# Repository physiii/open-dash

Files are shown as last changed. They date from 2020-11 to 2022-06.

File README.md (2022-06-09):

### Objective

Provide an open source platform for vehicle information and entertainment. 

Daughterboard firmware is designed around FreeRTOS. Supports CANbus and J1850 protocols and many functions such as HVAC control, battery monitoring, vehicle status and statistics over wifi. Uses driver circuits for various actuators around the car. 

Front end software is designed to run on Linux. I recommend Ubuntu for the main computer. 

GUI is made using NodeWebkit and communicates with a custom daughterboard for interfacing with the vehicle.

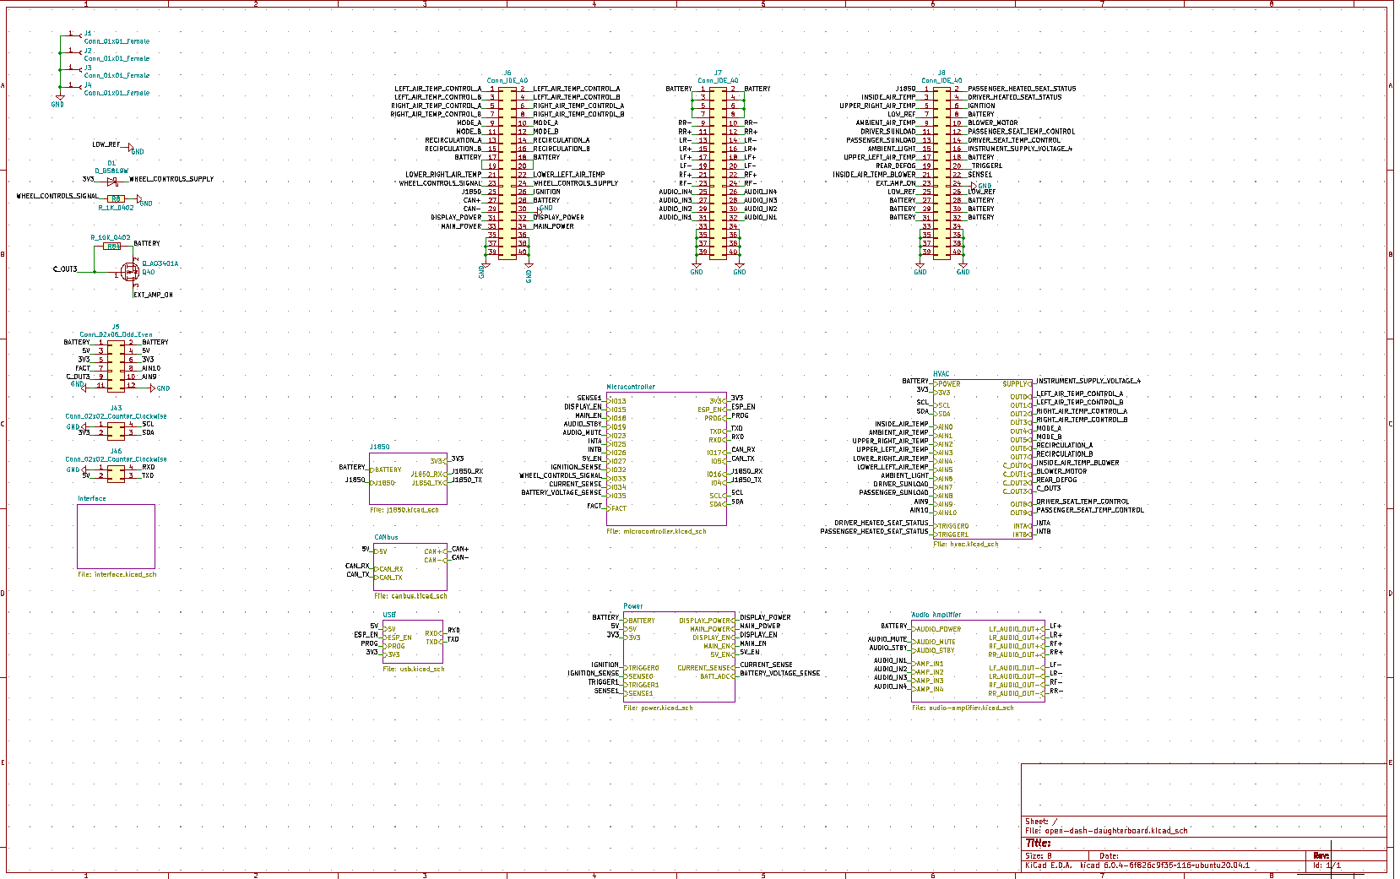
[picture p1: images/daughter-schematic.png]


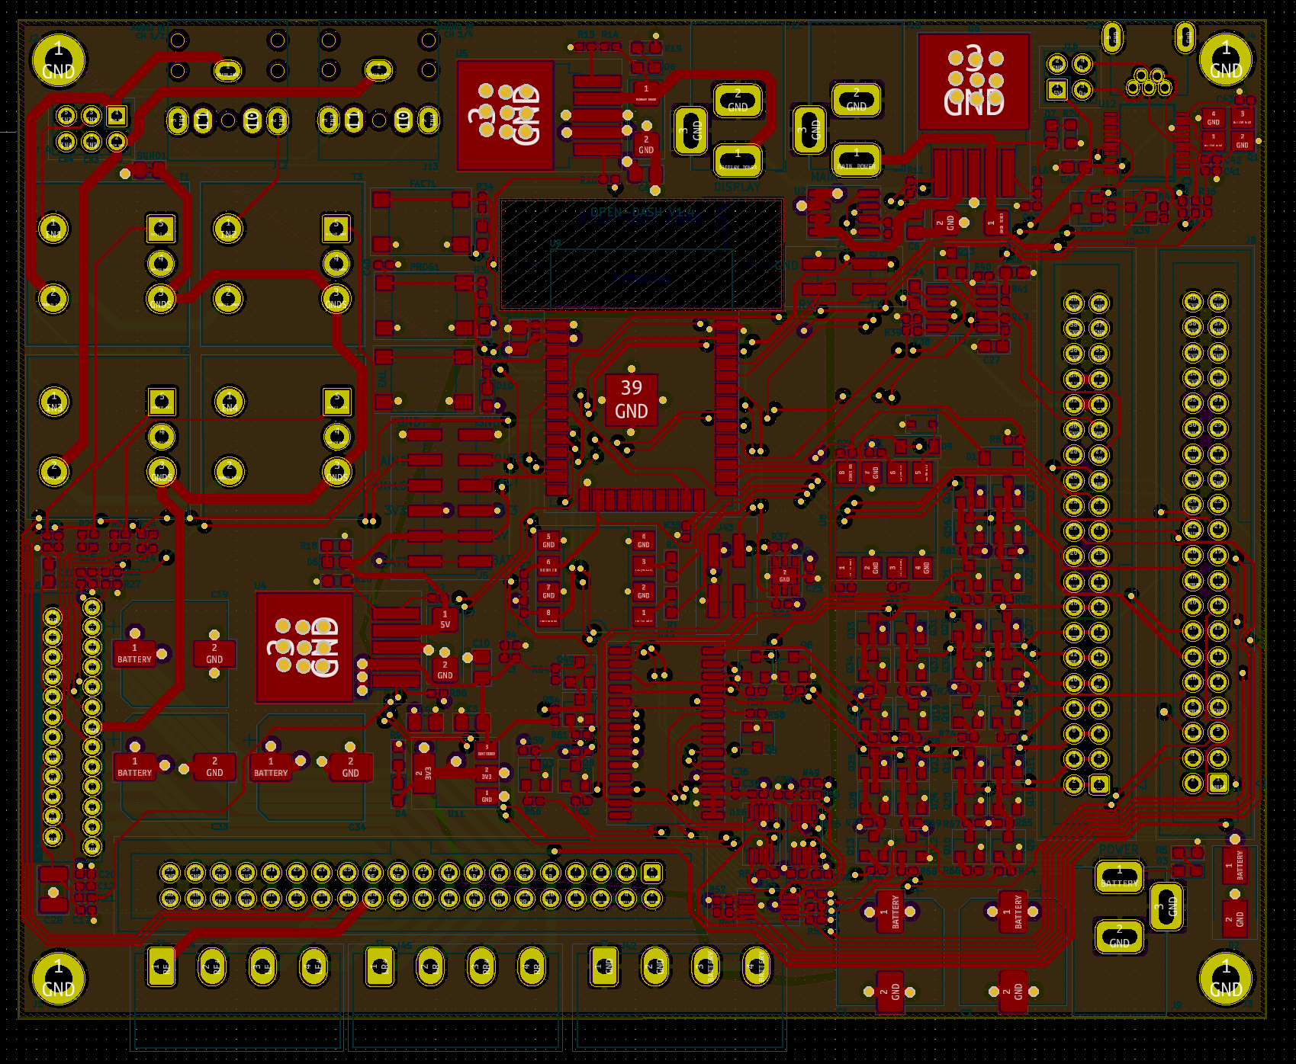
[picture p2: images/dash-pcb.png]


### Install OS
Download ubuntu 21.10 and create boot disk  
Press esc to get to boot menu  
Boot manager  
Choose flash drive  
Choose Install ubuntu
Choose erase disk and install ubuntu  
Remove flash drive and reboot  

### Setup OS
Set no keyring passwd  
Disable Power Savings   
sudo visudo /etc/sudoers: 
```
%sudo   ALL=(ALL:ALL) NOPASSWD:ALL  
```

```
sudo usermod -a -G dialout $USER
sudo usermod -a -G audio $USER
```
Add startup programs  
```
pm2 start /usr/local/src/open-dash/service/index.js --time --name dash
nw /usr/local/src/open-dash
```

### Display

Set scale to 200%  
Rotate to portrait mode
Settings > Appearance > Position on screen: Bottom
```
sudo cp /usr/local/src/open-dash/scripts/99-touch.rules /etc/udev/rules.d/99-touch.rules
```

### Install Dependencies
```
sudo apt install -y curl
curl -sL https://deb.nodesource.com/setup_14.x | sudo -E bash -
sudo apt update
```

```
sudo wget -qnc https://repo.nordvpn.com/deb/nordvpn/debian/pool/main/nordvpn-release_1.0.0_all.deb
sudo dpkg -i ./nordvpn-release_1.0.0_all.deb
```
```
wget -q -O - https://dl-ssl.google.com/linux/linux_signing_key.pub | sudo apt-key add -
echo 'deb [arch=amd64] http://dl.google.com/linux/chrome/deb/ stable main' | sudo tee /etc/apt/sources.list.d/google-chrome.list
sudo apt update
```

```
sudo apt-get -y install gnupg
wget -qO - https://www.mongodb.org/static/pgp/server-4.4.asc | sudo apt-key add -
echo "deb [ arch=amd64,arm64 ] https://repo.mongodb.org/apt/ubuntu focal/mongodb-org/4.4 multiverse" | sudo tee /etc/apt/sources.list.d/mongodb-org-4.4.list
```

```
sudo apt update && sudo apt upgrade -y

sudo apt install -y \
  tmux git nodejs sshfs nmap cmake pv vlc pithos gimp librecad resolvconf openssh-server \
  net-tools v4l-utils clementine net-tools kodi nordvpn vlc-plugin-bittorrent \
  libgconf-2-4 sshpass git nodejs dnsmasq hostapd tmux xdotool libudev-dev \
  python-setuptools python3-dev libssl-dev libasound2-dev nmap ffmpeg \
  build-essential cmake pkg-config libjpeg-dev libtiff5-dev libatomic1 \
  libavcodec-dev libavformat-dev libswscale-dev libv4l-dev libxvidcore-dev libx264-dev libfreetype6-dev \
  libatlas-base-dev gfortran python3-dev libavcodec-dev libavformat-dev python3-pip \
  libasound-dev portaudio19-dev libportaudio2 libportaudiocpp0 \
  google-chrome-stable speedtest-cli mongodb-org \

```

```
sudo npm install -g nw-gyp
sudo npm install -g pm2 --unsafe-perm=true --allow-root
sudo snap install atom --classic
sudo snap install blender --channel=beta --classic
```

```
sudo apt install -y apt-transport-https curl
sudo curl -fsSLo /usr/share/keyrings/brave-browser-archive-keyring.gpg https://brave-browser-apt-release.s3.brave.com/brave-browser-archive-keyring.gpg
echo "deb [signed-by=/usr/share/keyrings/brave-browser-archive-keyring.gpg arch=amd64] https://brave-browser-apt-release.s3.brave.com/ stable main"|sudo tee /etc/apt/sources.list.d/brave-browser-release.list
sudo apt update
sudo apt install -y brave-browser
```
### kicad
```
sudo add-apt-repository --yes ppa:js-reynaud/kicad-5.1
sudo apt update
sudo apt install -y --install-suggests kicad

mkdir ~/circuits
cd ~/circuits
git clone https://github.com/physiii/kicad-parts
# add symbol and footprint paths
```
### esp32
```
sudo ln -s /usr/bin/python3 /usr/bin/python

mkdir -p ~/esp
cd ~/esp
git clone --recursive https://github.com/espressif/esp-idf.git

cd ~/esp/esp-idf
./install.sh

echo "alias get_idf='. $HOME/esp/esp-idf/export.sh'" >> ~/.bashrc

source ~/.bashrc
get_idf

cd ~/esp
cp -r $IDF_PATH/examples/get-started/hello_world .
cd ~/esp/hello_world
idf.py set-target esp32
idf.py menuconfig
```

### audio
```
cd ~
git clone https://github.com/physiii/ardour-sessions

```
sudo nano /etc/security/limits.conf
```
  @audio          -       rtprio          99
```
```
sudo apt install -y qjackctl pulseaudio-module-jack libjack0 jackd jack-tools \
linux-lowlatency ardour a2jmidid libjack-dev pavucontrol \
```
## Jack
set interface  
Settings -> MIDI Driver: seq  
Options -> execute script after startup: pactl load-module module-jack-sink;pactl load-module module-jack-source;pactl set-default-sink jack_out  
Misc -> start JACK audio service on application startup  
```
pamcd set-default-sink jack_out
```
```
sudo apt install -y \
calf-plugins libtool autoconf libexpat1-dev libglib2.0-dev libfluidsynth-dev \
jackd libjack-dev libglade2-dev lv2-dev yoshimi ams \
blop caps cmt fil-plugins rev-plugins swh-plugins tap-plugins \
invada-studio-plugins-lv2 mda-lv2 swh-lv2 \
blepvco mcp-plugins omins so-synth-lv2 lingot \
```
## MIDI

```
pip3 install python-rtmidi pyserial mido
git clone https://github.com/physiii/wireless-midi
```

###  Popcorn
```
sudo chown -R ${USER}:${USER} /usr/local/src
cd /usr/local/src
git clone https://github.com/popcorn-official/popcorn-desktop
cd popcorn-desktop
sudo npm install -g gulp
npm install
gulp build
gulp run
nw .
```
### NW.JS
```
sudo chown -R ${USER}:${USER} /usr/local/src
cd /usr/local/src  
wget https://dl.nwjs.io/v0.54.0/nwjs-sdk-v0.54.0-linux-x64.tar.gz
tar -zxvf nwjs-sdk*  
cd nwjs-sdk*  
sudo ln -s /usr/local/src/nwjs-sdk-v0.54.0-linux-x64/nw /usr/bin/nw  
```
### Install Software
```
sudo chown -R ${USER}:${USER} /usr/local/src
cd /usr/local/src
git clone https://github.com/physiii/open-dash
cd open-dash
npm install
npm run build
```

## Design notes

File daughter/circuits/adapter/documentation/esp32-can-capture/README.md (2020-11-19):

this program just prints CAN frames so you can capture them with "make monitor"

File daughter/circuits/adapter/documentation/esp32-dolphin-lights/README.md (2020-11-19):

let a Dolphin drive the WS2812 LEDs via a serial BT connection to the ESP32

based in part on <https://github.com/FozzTexx/ws2812-demo>

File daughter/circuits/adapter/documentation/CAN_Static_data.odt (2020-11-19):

Listing of all IDs that were broadcasting the same data in a ~30 second period without changing, engine was running

Known static conditions:

Outside air temp: 103*F

Odometer: 904 miles

Time/date: 7:01am, Jan 1 2017

Gear: park

ESC mode: on

AC: on

AC fan: on

Speed: 0 mph

6314000: unknown: 0000000000000000

4294001: unknown: 0000B30000000000

421400B: unknown: 00863E0400000000

6214000: Lights, maybe: 0404400000570B00

C054003: unknown: 047005AE815A0000

63D4000: unknown: 9F56000018B70000

4394000: unknown: 00000002

4214006: ESC mode: 0000000000000006

621400A: unknown: 0400

6254000: unknown: 80FFFF00FFFFFF00

6314003: unknown: 0010700000000000

621401A: unknown: 0005010092000000

2214000: unknown: 000000000000

A3D4003: unknown: 2CA51004D0000000

6284000: Steering wheel controls: 0000000000000000

A354003: unknown: 2CA51004D0000000

6314018: Reverse: C000000000000000

62BBF00: unknown: 0000000000000000

A194003: unknown: 0000400000000000

C394003: unknown: C302000008016000

E094000: unknown: 001E05401C4B

E094003: unknown: 001E

E09400A: unknown: 001E

E094018: unknown: 001E

E09401A: unknown: 000E

E094020: unknown: 000A

2294000: unknown: 0000000000000000

C214003: Time/date string: 070101012017

*********************************************************

Another static dump, but with engine off (only one new ID):

4294001: unknown: 0000B30000000000

421400B: unknown: 00863E0400000000

3029100: unknown: 0000000000000000

621401A: unknown: 0005010092000000

4214001: unknown: 0081508B00000000

6214000: Lights, maybe: 0404480000570B00

621400A: unknown: 0400

C054003: unknown: 047005AE895A0000

63D4000: unknown: 9F4F00001AB70000

4394000: unknown: 00000002

4214006: ESC mode: 0000000000000000

6254000: unknown: 00FFFF00FFFFFF00

6314003: unknown: 0010700000000000

2214000: unknown: 000000000000

A3D4003: unknown: 2CA5100500000000

6284000: Steering wheel controls: 0000000000000000

A354003: unknown: 2CA5100500000000

62BBF00: unknown: 0000000000000000

A194003: unknown: 0000400000000000

C394003: unknown: C302000008016000

E094000: Key/ignition status probably: 001E05401C4B

E09400A: unknown: 001E

E094003: unknown: 001E

E094018: unknown: 001E

E09401A: unknown: 000E

E094020: unknown: 000A

6314018: Reverse: C000000000000000

2294000: unknown: 0000000000000000

C214003: Time/date string: 070701012017

***********************************************

IDs that change upon pressing brake:

4294001

421400B

2214000

63D4000

4214001 is more or less static with engine off, but does change as brake pedal is pressed. However, it changes constantly when engine is running. Perhaps this is brake booster pressure.

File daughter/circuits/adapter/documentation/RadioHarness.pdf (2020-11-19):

# Connector: Amp PA66−GF35 (PBT−GF15)

# > PBT−GF15 < B1

### RETURN (COMMON)

### CAMERA

### CAMERA SIGNAL

### SHIELD

### CAMERA

CAN
HIGH

LOW

CAN

CHASSIS
GROUND

12vDC
UNSWITCHED

# SPEAKERS

# NEG

# POS

RR− | FR− | FL− | RL−

− MIC +

BL

R REF
IN IN

DET
IN

L
IN

# AUX

3 | 4 | 5

13 18

29

1 | 2 | 6 | 7 | 8 | 9 | 10
11 | 12 | 14 | 15 | 16 | 17 | 19 | 20
21 | 22 | 23 | 24 | 25 | 26 | 27 | 28 | 30
31 | 32 | 33 | 34 | 35 | 36 | 37 | 38 | 39 | 40 | 49 | 50 | 51 | 52
45 | 46 | 47 | 48
41 | 42 | 43 | 44

RADIO ON
(NC)

+
(NC)

NOT CONNECTED ON 2018+ MODELS. LATE MODELS USE CANBUS MESSAGES TO SEND IGNITION/KEY STATUS

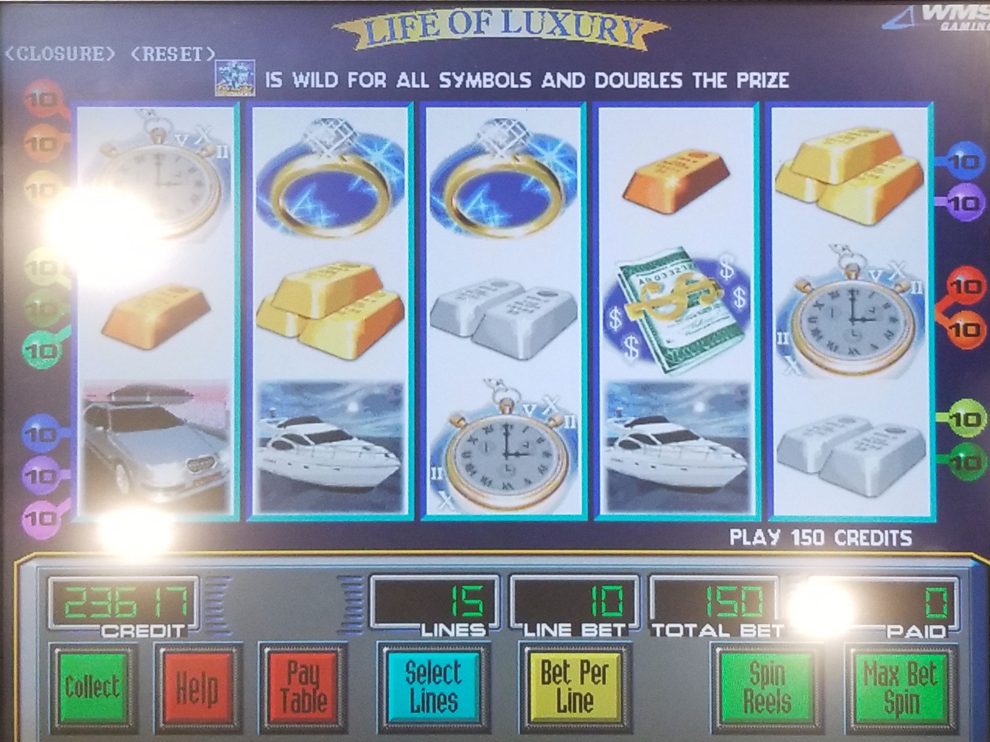
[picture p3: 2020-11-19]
src/assets/game-board-mockup.jpg

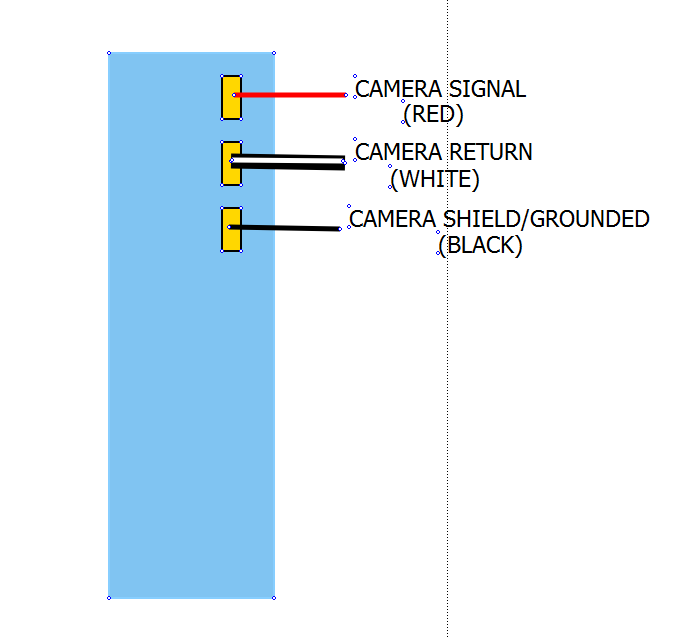
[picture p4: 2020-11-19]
daughter/circuits/adapter/documentation/CameraHarnessRadio_C.png

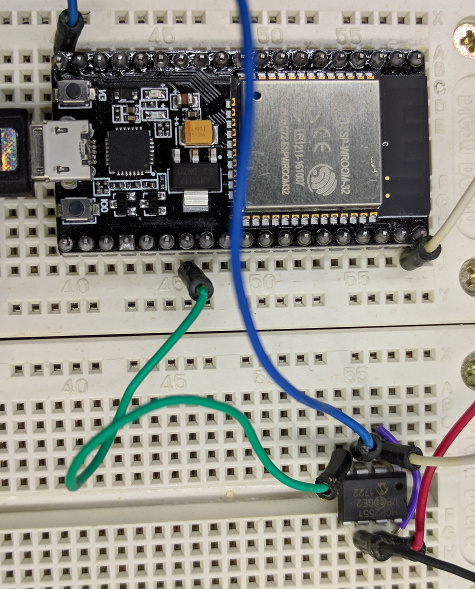
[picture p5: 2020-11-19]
daughter/circuits/adapter/documentation/ESP32-MCP2551.jpg

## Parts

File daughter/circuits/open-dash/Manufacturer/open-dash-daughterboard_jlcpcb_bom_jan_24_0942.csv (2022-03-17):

Comment | Designator | Footprint | LCSC
C_0.1uF | C13,C14,C15,C16,C21,C25 | Capacitor_SMD:C_0402_1005Metric_Pad0.74x0.62mm_HandSolder | C1525
C_470nF | C18 | Capacitor_SMD:C_0603_1608Metric_Pad1.08x0.95mm_HandSolder | C1623
C_470uF | C1,C2,C19,C33,C34 | Capacitor_SMD:CP_Elec_10x10 | C3350
C_1uF | C11,C12,C20,C23,C40 | Capacitor_SMD:C_0402_1005Metric_Pad0.74x0.62mm_HandSolder | C52923
C_0.1uF | C24 | Capacitor_SMD:C_0603_1608Metric_Pad1.08x0.95mm_HandSolder | C14663
C_470pF | C26,C27 | Capacitor_SMD:C_0603_1608Metric_Pad1.08x0.95mm_HandSolder | C1537
C_1nF_0402 | C37 | Capacitor_SMD:C_0402_1005Metric_Pad0.74x0.62mm_HandSolder | C1523
C_10uF | C3,C4,C5,C6,C10,C17,C22 | Capacitor_SMD:C_0805_2012Metric_Pad1.18x1.45mm_HandSolder | C15850
C_100nF_0402 | C35,C36,C38,C39,C41 | Capacitor_SMD:C_0402_1005Metric_Pad0.74x0.62mm_HandSolder | C1525
C_27pF_0402 | C42,C43 | Capacitor_SMD:C_0402_1005Metric_Pad0.74x0.62mm_HandSolder | C1557
C_22uF | C44 | Capacitor_SMD:C_0603_1608Metric_Pad1.08x0.95mm_HandSolder | C59461
C_10uF_Ta | C7,C8,C9 | Capacitor_Tantalum_SMD:CP_EIA-6032-15_Kemet-U_Pad2.25x2.35mm_HandSolder | C116748
D_B5819W | D1,D9 | Diode_SMD:D_SOD-123 | C8598
LED_G | D10,D11,D12 | Diode_SMD:D_0603_1608Metric_Pad1.05x0.95mm_HandSolder | C72041
PESD1CAN-UX | D13 | Package_TO_SOT_SMD:SOT-23 | C152727
D_Zener | D2 | Diode_SMD:D_SMB_Handsoldering | C8835
LED_G | D3,D4,D5,D6,D7 | LED_SMD:LED_0603_1608Metric_Pad1.05x0.95mm_HandSolder | C72041
MM3Z8V2 | D8 | Diode_SMD:D_SOD-323 | C216751
SW_PUSH | FACT1,PROG1,EN1 | Button_Switch_SMD:SW_SPST_PTS645 | C127509
Conn_01x01_Female | J1,J2,J3,J4,J38,J39,J40,J41 | Open_Automation:Mount_Hole
Barrel_Jack_OD5.5_ID2.5 | J9,J10,J11 | Open_Automation:BarrelJack_OD5.5_ID2.5
AudioJack_3.5TRS | J12,J13 | Open_Automation:AudioJack_SJ1-3525N
Conn_02x03_Odd_Even | J14 | Connector_PinHeader_2.54mm:PinHeader_2x03_P2.54mm_Vertical
USB_MINI_B | J15 | Open_Automation:USB-mini-B-0548190519
Conn_02x02_Counter_Clockwise | J16 | Connector_PinHeader_2.54mm:PinHeader_2x02_P2.54mm_Vertical
Conn_01x08 | J17,J19,J23,J25,J29,J31 | Connector_PinHeader_2.54mm:PinHeader_1x08_P2.54mm_Vertical
C1 | J18 | Open_Automation:Conn_HVAC
C2 | J24 | Open_Automation:Conn_HVAC
Conn_01x20 | J20,J21,J26,J28,J33,J34 | Connector_PinHeader_2.54mm:PinHeader_1x20_P2.54mm_Vertical
C3 | J30 | Open_Automation:Conn_HVAC
Conn_01x12 | J35,J37 | Connector_PinHeader_2.54mm:PinHeader_1x12_P2.54mm_Vertical
STEREO | J36 | Open_Automation:Conn_Stereo
Conn_02x02_Counter_Clockwise | J43,J46 | Connector_PinHeader_2.54mm:PinHeader_2x02_P2.54mm_Vertical_SMD
Terminal_01x04 | J42,J44,J45 | Open_Automation:Terminal_1,5_4-G-5.08_1x04_P5.08mm_Horizontal
Conn_02x06_Odd_Even | J5 | Connector_PinHeader_2.54mm:PinHeader_2x06_P2.54mm_Vertical_SMD
Conn_IDE_40 | J6,J7,J8,J22,J27,J32 | Connector_IDC:IDC-Header_2x20_P2.54mm_Vertical
Crystal_12Mhz | Q1 | Crystal:Crystal_SMD_3225-4Pin_3.2x2.5mm_HandSoldering | C9002
Q_AO3400A | Q14,Q20,Q24,Q26,Q28,Q30,Q32,Q34,Q36,Q38 | Package_TO_SOT_SMD:SOT-23 | C20917
Q_SS8050 | Q2 | Package_TO_SOT_SMD:SOT-23 | C2150
Q_SS8550 | Q39 | Package_TO_SOT_SMD:SOT-23 | C8542
Q_NPN_BEC | Q3,Q4,Q5,Q6,Q7,Q8,Q9,Q10,Q12,Q13,Q15,Q16,Q18,Q19,Q21,Q22 | Package_TO_SOT_SMD:SOT-23 | C2150
Q_AO3401A | Q11,Q17,Q23,Q25,Q27,Q29,Q31,Q33,Q35,Q37,Q40 | Package_TO_SOT_SMD:SOT-23 | C15127
R_6.8K | R13 | Resistor_SMD:R_0603_1608Metric_Pad0.98x0.95mm_HandSolder | C23212
R_20K | R12,R14,R16 | Resistor_SMD:R_0402_1005Metric_Pad0.72x0.64mm_HandSolder | C25765
R_2.2K | R15,R17 | Resistor_SMD:R_0402_1005Metric_Pad0.72x0.64mm_HandSolder | C4190
R_1K | R1,R2,R5,R9,R18,R19,R20 | Resistor_SMD:R_0603_1608Metric_Pad0.98x0.95mm_HandSolder | C21190
R_47K_0402 | R22,R27 | Resistor_SMD:R_0402_1005Metric_Pad0.72x0.64mm_HandSolder | C25792
R_100 | R29,R41,R42 | Resistor_SMD:R_0402_1005Metric_Pad0.72x0.64mm_HandSolder | C25076
R_100K_0402 | R3 | Resistor_SMD:R_0402_1005Metric_Pad0.72x0.64mm_HandSolder | C25741
R_4.7K | R38,R40 | Resistor_SMD:R_0402_1005Metric_Pad0.72x0.64mm_HandSolder | C25900
R_1K_0402 | R8,R23,R24,R25,R26,R28,R30,R31,R43,R44 | Resistor_SMD:R_0402_1005Metric_Pad0.72x0.64mm_HandSolder | C11702
R_10K_0402 | R4,R6,R7,R10,R11,R21,R32,R33,R34,R35,R36,R37,R39,R45,R46,R47,R48,R49,R50,R51,R52,R53,R54,R55,R56,R57,R58,R59,R60,R61,R62,R63,R64,R65,R66,R67,R68,R69,R70,R71,R72,R73,R74,R75,R76,R77,R78,R79,R80,R81,R82,R83,R84,R85,R86 | Resistor_SMD:R_0402_1005Metric_Pad0.72x0.64mm_HandSolder | C25744
SGND_CONN | SGND1 | Open_Automation:SGND_CONN
Audio_Transformer | T1,T2,T3,T4 | Open_Automation:Audio_Transformer
Opto_TLP521 | U1,U8 | Package_DIP:SMDIP-8_W9.53mm | C722233
Temp_Hum_HDC1080DMBR | U10 | Package_DFN_QFN:DFN-6-1EP_3x3mm_P1mm_EP1.5x2.4mm | C82227
REG_AMS1117-3.3 | U11 | Package_TO_SOT_SMD:SOT-223-3_TabPin2 | C347222
CH340T(SSOP20W) | U12 | Open_Automation:SSOP-20W | C8689
MCP23017_SS | U13 | Package_SO:SOIC-28W_7.5x17.9mm_P1.27mm | C47023
ADC_ADS1015 | U14,U15,U16 | Package_SO:MSOP-10_3x3mm_P0.5mm | C37593
ACS711 | U2 | Package_SO:SOIC-8_3.9x4.9mm_P1.27mm | C10681
CAN_MCP2551-I-SN | U3 | Package_SO:SOIC-8_3.9x4.9mm_P1.27mm | C7376
MIC29302WU | U4,U5,U6 | Package_TO_SOT_SMD:TO-263-5_TabPin3 | C11149
TDA7851F | U7 | Open_Automation:Flexiwatt25-V
ESP32-WROOM-32 | U9 | RF_Module:ESP32-WROOM-32 | C82899

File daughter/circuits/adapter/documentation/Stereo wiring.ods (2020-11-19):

Pin # | Cable Color | Name/Function | Possible function/notes
1 | n/c
2 | Blue/Black | Can +
3 | n/c
4 | n/c
5 | n/c
6 | Green | Aux R | confirmed
7 | Black | Aux Ref
8 | n/c
9 | n/c
10 | n/c
11 | n/c
12 | White/Purple | Can -
13 | Yellow | BL | 12V Battery/Memory
14 | n/c
15 | n/c
16 | White | Aux L | confirmed
17 | Red | Aux DET | 12V Accessory
18 | Black | Ground? | Ground
19 | n/c
20 | n/c
21 | n/c
22 | n/c
23 | n/c
24 | n/c
25 | n/c
26 | n/c
27 | n/c
28 | n/c
29 | Black | Mic -
30 | White | Mic +
31 | Red | Camera Signal
32 | Ground/bare cable | Camera Shield/Ground
33 | Black | Camera Return
34 | n/c
35 | n/c
37 | n/c
37 | n/c
38 | n/c
39 | n/c
40 | n/c
41 | n/c | Radio ON
42 | n/c | 15s +
43 | Black | Ground
44 | Red/Yellow | 30 (+)
45 | Green | Right Rear Speaker (+)
46 | purple/red | Right Front Speaker (+)
47 | Yellow | Left Front Speaker (+)
48 | Orange | Left Rear Speaker (+)
49 | Green/Black | Right Rear Speaker ( - )
50 | Purple/Black | Right Front Speaker ( - )
51 | Yellow/Black | Left Front Speaker ( - )
52 | Orange/Black | Left Rear Speaker ( - )
Blue GPS | 2.188 Kohm
White Radio | open circuit no capacitance

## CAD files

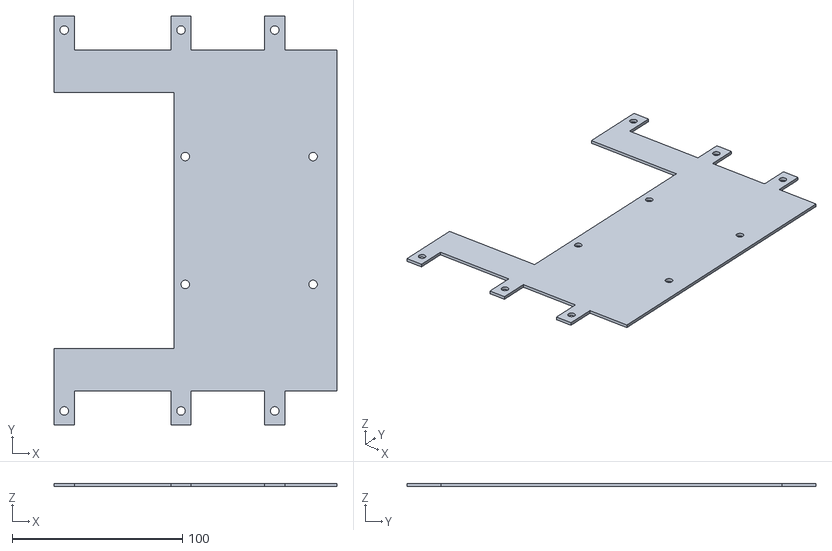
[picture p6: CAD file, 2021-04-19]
model/Corvette/mount_plate.stl
166.0 x 240.0 x 2.00

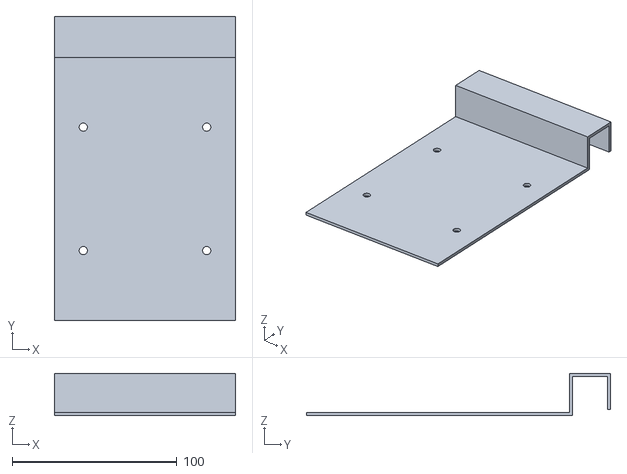
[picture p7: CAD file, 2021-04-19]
model/Dodge/mounting_plate.stl
110.0 x 184.8 x 25.7

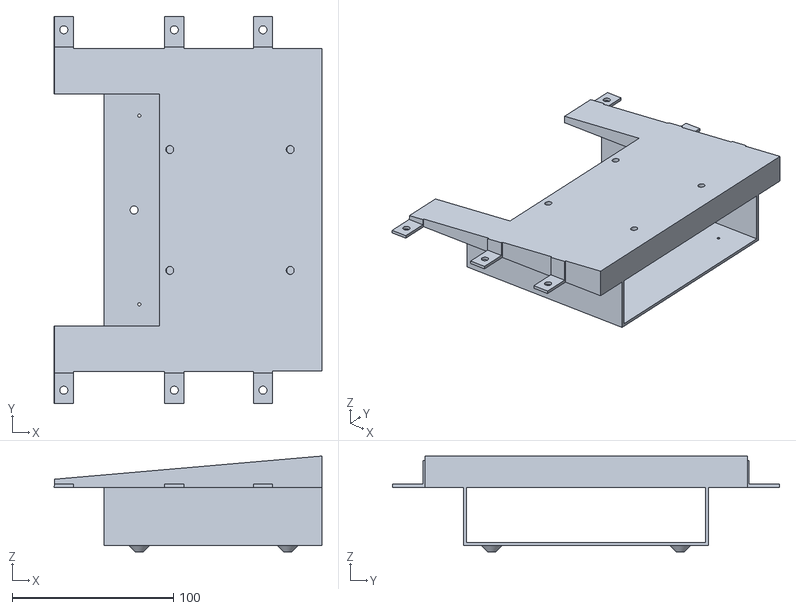
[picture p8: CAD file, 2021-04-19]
model/Corvette/corvette.stl
166.0 x 240.0 x 59.5

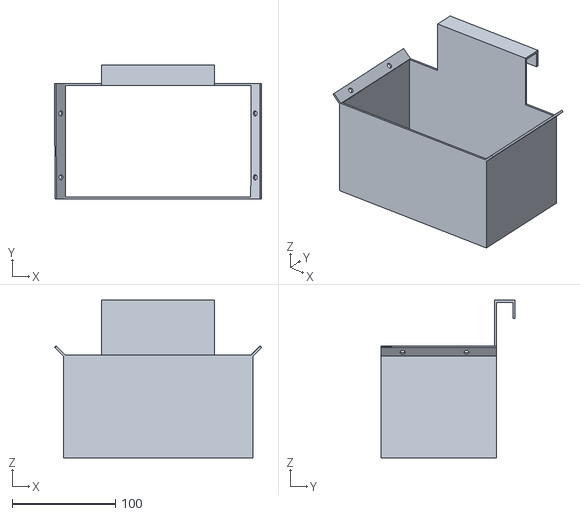
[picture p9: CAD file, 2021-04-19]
model/Dodge/mounting_bracket.stl
201.0 x 130.0 x 153.0

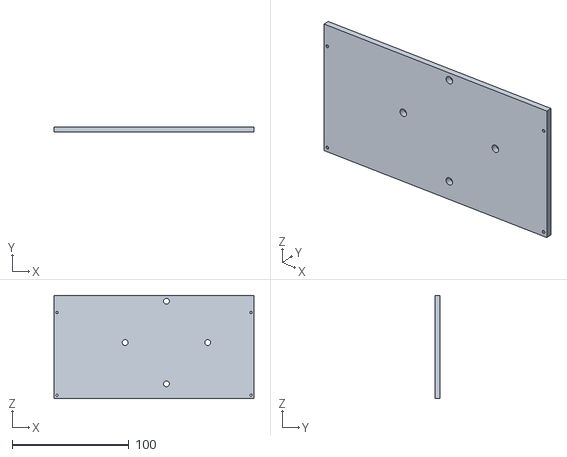
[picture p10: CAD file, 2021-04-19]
model/Dodge/divider.stl
171.1 x 4.01 x 88.4

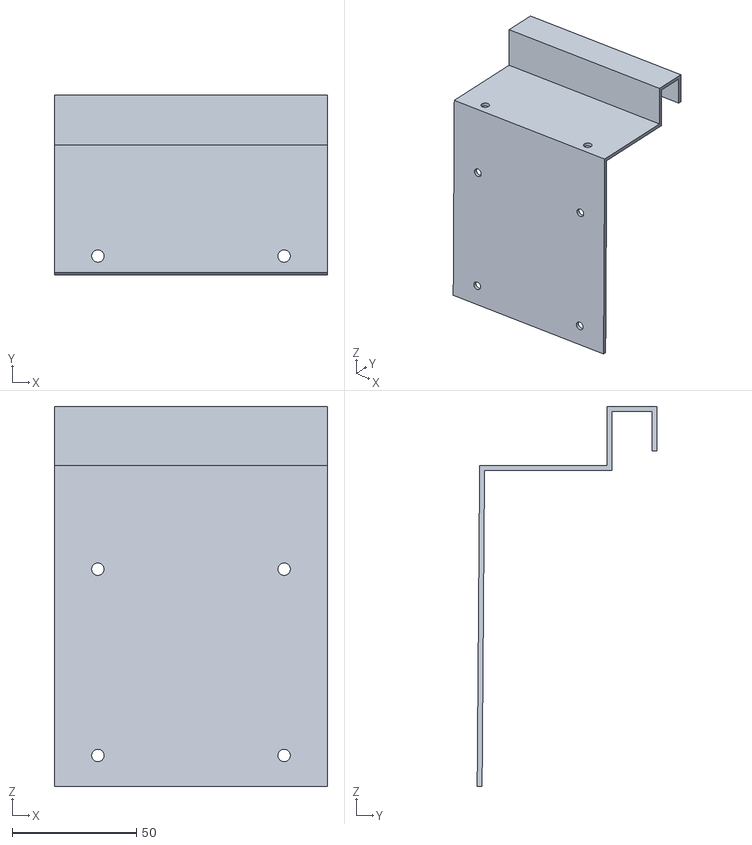
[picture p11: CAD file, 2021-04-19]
model/Dodge/mount_display_portrait.stl
110.0 x 72.4 x 153.0

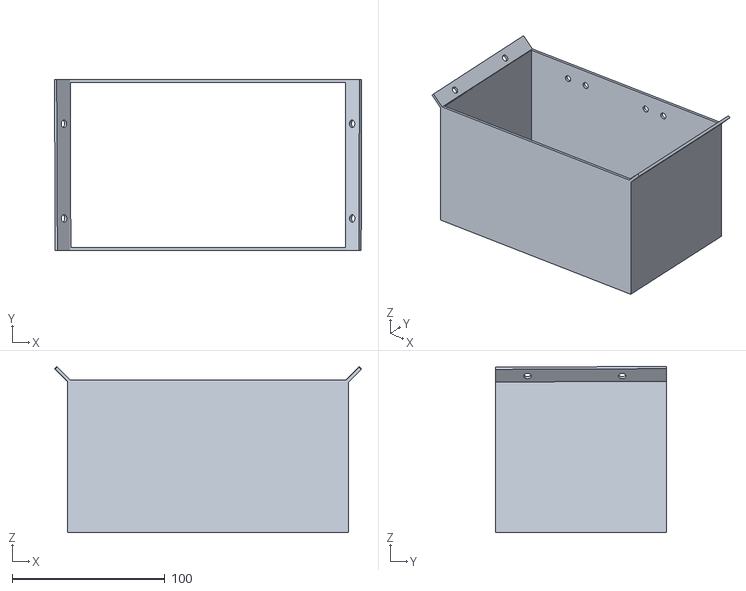
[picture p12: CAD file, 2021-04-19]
model/Dodge/receiver.stl
201.0 x 112.0 x 108.7

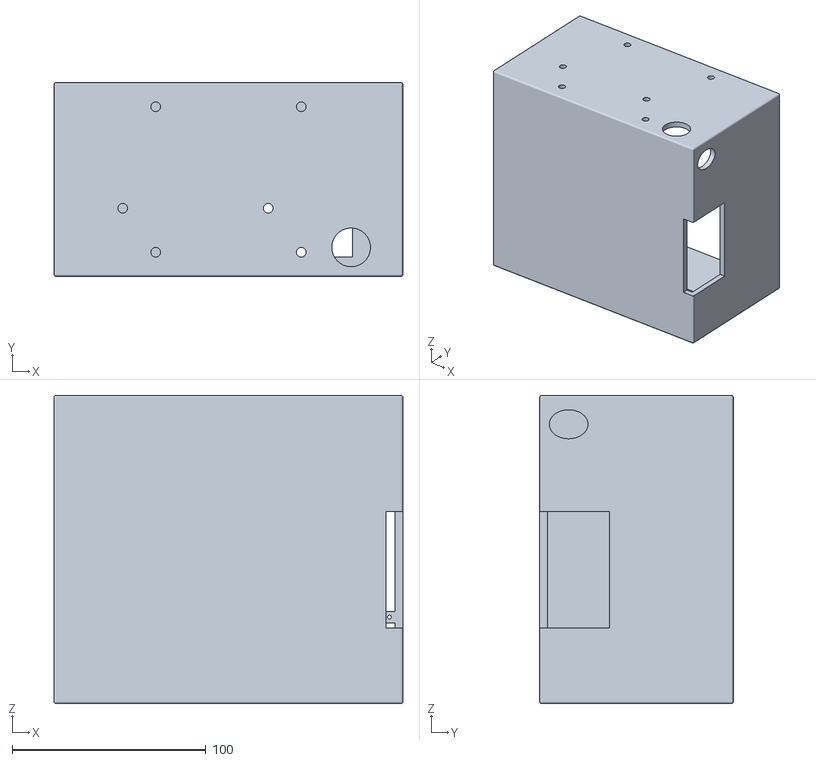
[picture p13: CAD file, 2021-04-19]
model/Dodge/box.stl
180.0 x 100.0 x 159.0

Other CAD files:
model/Corvette/corvette.blend
model/Dodge/open-dash-landscape.blend
model/Dodge/open-dash-portrait.blend
model/Dodge/open-dash.blend

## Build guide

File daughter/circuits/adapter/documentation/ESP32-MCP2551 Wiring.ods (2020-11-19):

ESP32 |  | MCP2551 |  | ESP32-MCP2551.jpg Wire Color
19 | VDD5V | 3 | Vdd | Blue
1 | GND | 2 | Vss | White
14 | GPIO_4 | 4 | RXD | Green
 |  | 5 | Rs | Purple (connects to self Pin 2 Vss)
 |  | 6 | CAN_H | Red
 |  | 7 | CAN_L | Black

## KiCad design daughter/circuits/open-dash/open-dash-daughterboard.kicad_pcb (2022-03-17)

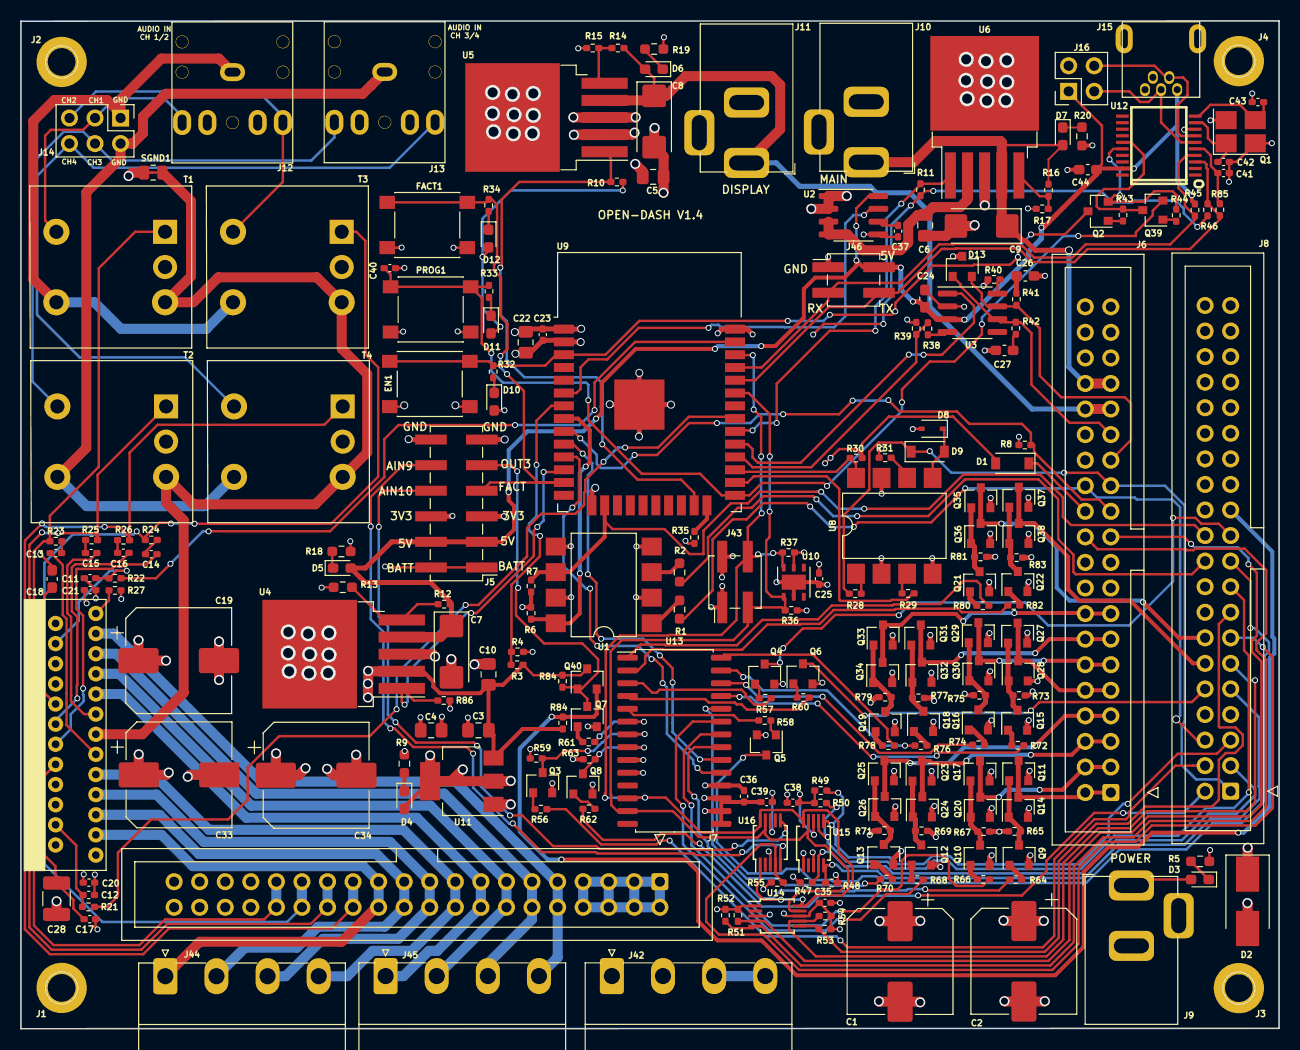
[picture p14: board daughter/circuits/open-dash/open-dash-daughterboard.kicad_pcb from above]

Board: 4 copper layers, 125.0 x 100.1 mm, 225 parts (0 on the bottom side), 170 nets.

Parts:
C1, C2, C19, C33, C34: C_470uF; CP_Elec_10x10
C3, C4, C5, C6, C10, C22: C_10uF; C_0805_2012Metric_Pad1.18x1.45mm_HandSolder
C7, C8, C9: C_10uF_Ta; CP_EIA-6032-15_Kemet-U_Pad2.25x2.35mm_HandSolder
C11, C12, C17, C20, C23, C40: C_1uF; C_0402_1005Metric_Pad0.74x0.62mm_HandSolder
C13, C14, C15, C16, C21, C25: C_0.1uF; C_0402_1005Metric_Pad0.74x0.62mm_HandSolder
C18: C_470nF; C_0603_1608Metric_Pad1.08x0.95mm_HandSolder
C24: C_0.1uF; C_0603_1608Metric_Pad1.08x0.95mm_HandSolder
C26, C27: C_470pF; C_0603_1608Metric_Pad1.08x0.95mm_HandSolder
C28: C_47uF; C_1210_3225Metric_Pad1.33x2.70mm_HandSolder
C35, C36, C38, C39, C41: C_100nF_0402; C_0402_1005Metric_Pad0.74x0.62mm_HandSolder
C37: C_1nF_0402; C_0402_1005Metric_Pad0.74x0.62mm_HandSolder
C42, C43: C_27pF_0402; C_0402_1005Metric_Pad0.74x0.62mm_HandSolder
C44: C_22uF; C_0603_1608Metric_Pad1.08x0.95mm_HandSolder
D1, D9: D_B5819W; D_SOD-123
D2: D_Zener; D_SMB_Handsoldering
D3, D4, D5, D6, D7: LED_G; LED_0603_1608Metric_Pad1.05x0.95mm_HandSolder
D8: MM3Z8V2; D_SOD-323
D10, D11, D12: LED_G; D_0603_1608Metric_Pad1.05x0.95mm_HandSolder
D13: PESD1CAN-UX; SOT-23
EN1: SW_PUSH; SW_SPST_PTS645
FACT1: SW_PUSH; SW_SPST_PTS645
J1, J2, J3, J4: Conn_01x01_Female; Mount_Hole
J5: Conn_02x06_Odd_Even; PinHeader_2x06_P2.54mm_Vertical_SMD
J6, J7, J8: Conn_IDE_40; IDC-Header_2x20_P2.54mm_Vertical
J9, J10, J11: Barrel_Jack_OD5.5_ID2.5; BarrelJack_OD5.5_ID2.5
J12, J13: AudioJack_3.5TRS; AudioJack_SJ1-3525N
J14: Conn_02x03_Odd_Even; PinHeader_2x03_P2.54mm_Vertical
J15: USB_MINI_B; USB-mini-B-0548190519
J16: Conn_02x02_Counter_Clockwise; PinHeader_2x02_P2.54mm_Vertical
J42, J44, J45: Terminal_01x04; Terminal_1,5_4-G-5.08_1x04_P5.08mm_Horizontal
J43, J46: Conn_02x02_Counter_Clockwise; PinHeader_2x02_P2.54mm_Vertical_SMD
PROG1: SW_PUSH; SW_SPST_PTS645
Q1: Crystal_12Mhz; Crystal_SMD_3225-4Pin_3.2x2.5mm_HandSoldering
Q2: Q_SS8050; SOT-23
Q3, Q4, Q5, Q6, Q7, Q8, Q9, Q10, Q12, Q13, Q15, Q16, Q18, Q19, Q21, Q22: Q_NPN_BEC; SOT-23
Q11, Q17, Q23, Q25, Q27, Q29, Q31, Q33, Q35, Q37, Q40: Q_AO3401A; SOT-23
Q14, Q20, Q24, Q26, Q28, Q30, Q32, Q34, Q36, Q38: Q_AO3400A; SOT-23
Q39: Q_SS8550; SOT-23
R1, R2, R5, R9, R18, R19, R20: R_1K; R_0603_1608Metric_Pad0.98x0.95mm_HandSolder
R3: R_100K_0402; R_0402_1005Metric_Pad0.72x0.64mm_HandSolder
R4, R6, R7, R10, R11, R21, R32, R33, R34, R35, R36, R37, R39, R45, R46, R47, R48, R49, R50, R51, R52, R53, R54, R55, R56, R57, R58, R59, R60, R61, R62, R63, R64, R65, R66, R67, R68, R69, R70, R71, R72, R73, R74, R75, R76, R77, R78, R79, R80, R81, R82, R83, R84#2, R85, R86: R_10K_0402; R_0402_1005Metric_Pad0.72x0.64mm_HandSolder
R8, R23, R24, R25, R26, R28, R30, R31, R43, R44, R84: R_1K_0402; R_0402_1005Metric_Pad0.72x0.64mm_HandSolder
R12, R14, R16: R_20K; R_0402_1005Metric_Pad0.72x0.64mm_HandSolder
R13: R_6.8K; R_0603_1608Metric_Pad0.98x0.95mm_HandSolder
R15, R17: R_2.2K; R_0402_1005Metric_Pad0.72x0.64mm_HandSolder
R22, R27: R_47K_0402; R_0402_1005Metric_Pad0.72x0.64mm_HandSolder
R29, R41, R42: R_100; R_0402_1005Metric_Pad0.72x0.64mm_HandSolder
R38, R40: R_4.7K; R_0402_1005Metric_Pad0.72x0.64mm_HandSolder
SGND1: SGND_CONN
T1, T2, T3, T4: Audio_Transformer
U1, U8: Opto_TLP521; SMDIP-8_W9.53mm
U2: ACS711; SOIC-8_3.9x4.9mm_P1.27mm
U3: CAN_MCP2551-I-SN; SOIC-8_3.9x4.9mm_P1.27mm
U4, U5, U6: MIC29302WU; TO-263-5_TabPin3
U7: TDA7851F; Flexiwatt25-V
U9: ESP32-WROOM-32
U10: Temp_Hum_HDC1080DMBR; DFN-6-1EP_3x3mm_P1mm_EP1.5x2.4mm
U11: REG_AMS1117-3.3; SOT-223-3_TabPin2
U12: CH340T(SSOP20W); SSOP-20W
U13: MCP23017_SS; SOIC-28W_7.5x17.9mm_P1.27mm
U14, U15, U16: ADC_ADS1015; MSOP-10_3x3mm_P0.5mm

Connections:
/3V3: C4.1, C22.1, C23.1, C25.1, C35.1, C36.1, C38.1, C39.1, D1.2, D4.2, D10.2, D11.2, D12.2, J5.5, J5.6, J43.2, R6.2, R7.2, R10.2, R11.2, R30.1, R36.1, R37.2, R46.2, R47.2, R48.2, R49.2, R50.2, R51.2, R52.2, R53.2, R54.2, R55.2, R59.2, R63.2, R86.2, U9.2, U10.5, U11.2, U13.9, U13.18, U14.1, U14.8, U15.8, U16.8
/5V: C7.1, C24.1, C44.1, D5.2, J5.3, J5.4, J15.1, J16.1, J46.2, R12.1, R45.1, U2.8, U3.3, U4.4, U12.19
/5V_EN: R86.1, U4.1, U9.12
/AIN9: J5.10, U16.5
/AIN10: J5.8, U16.6
/AMBIENT_AIR_TEMP: J8.9, R48.1, U15.5
/AMBIENT_LIGHT: J8.15, R53.1, U14.6
/AUDIO_IN1: J7.31, J7.32, R23.2, T1.5
/AUDIO_IN2: J7.29, J7.30, R24.2, T3.5
/AUDIO_IN3: J7.27, J7.28, R25.2, T2.5
/AUDIO_IN4: J7.25, J7.26, R26.2, T4.5
/AUDIO_MUTE: R22.2, U9.37
/AUDIO_STBY: R21.1, U9.31
/Audio Amplifier/AC_GND: C18.1, U7.16
/Audio Amplifier/AUDIO_GND1: J12.1, J14.1, T1.2, T3.2
/Audio Amplifier/AUDIO_GND2: J13.1, J14.2, T2.2, T4.2
/Audio Amplifier/IN1: J12.3, J14.3, T1.1
/Audio Amplifier/IN2: J12.2, J14.5, T3.1
/Audio Amplifier/IN3: J13.3, J14.4, T2.1
/Audio Amplifier/IN4: J13.2, J14.6, T4.1
/Audio Amplifier/MUTE: C11.2, R22.1, U7.22
/Audio Amplifier/OD: R27.2, U7.25
/Audio Amplifier/STBY: C12.2, R21.2, U7.4
/Audio Amplifier/SVR: C17.1, C28.1, U7.10
/BATTERY: C1.1, C2.1, C3.1, C5.1, C10.1, C19.1, C20.2, C21.1, C33.1, C34.1, D2.1, D3.2, J5.1, J5.2, J6.17, J6.18, J6.19, J6.20, J6.28, J7.1, J7.2, J7.3, J7.4, J7.5, J7.6, J7.7, J7.8, J8.8, J8.18, J8.27, J8.28, J8.29, J8.30, J8.31, J8.32, J9.1, J42.3, J42.4, Q11.2, Q17.2, Q23.2, Q25.2, Q27.2, Q29.2, Q31.2, Q33.2, Q35.2, Q37.2, Q40.3, R3.1, R31.1, R65.2, R67.2, R69.2, R71.2, R73.2, R75.2, R77.2, R79.2, R81.2, R83.2, R84.1, R84#2.2, U2.1, U2.2, U4.2, U5.2, U7.6, U7.20, U11.3
/BATTERY_VOLTAGE_SENSE: R3.2, R4.1, U9.7
/BLOWER_MOTOR: J8.10, Q6.3
/CAN+: D13.2, J6.27, R41.2, U3.7
/CAN-: D13.1, J6.29, R42.2, U3.6
/CAN_RX: R38.1, R39.2, U9.28
/CAN_TX: U3.1, U9.29
/CANbus/RX: R38.2, U3.4
/CURRENT_SENSE: U2.7, U9.6
/C_OUT3: J5.9, Q7.3, Q40.1, R84#2.1
/DISPLAY_EN: R10.1, U5.1, U9.23
/DISPLAY_POWER: C8.1, D6.2, J6.31, J6.32, J11.1, R14.1, U5.4
/DRIVER_HEATED_SEAT_STATUS: J8.4, R56.1
/DRIVER_SEAT_TEMP_CONTROL: J8.14, Q35.3, Q36.3
/DRIVER_SUNLOAD: J8.11, R54.1, U14.7
/ESP_EN: EN1.1, Q2.3, R32.1, U9.3
/EXT_AMP_ON: J8.23, Q40.2, R84.2
/FACT: FACT1.1, J5.7, R34.1, U9.13
/HVAC/A0: R64.1, U13.21
/HVAC/A1: R66.1, U13.22
/HVAC/A2: R68.1, U13.23
/HVAC/A3: R70.1, U13.24
/HVAC/A4: R72.1, U13.25
/HVAC/A5: R74.1, U13.26
/HVAC/A6: R76.1, U13.27
/HVAC/A7: R78.1, U13.28
/HVAC/B0: R80.1, U13.1
/HVAC/B1: R82.1, U13.2
/HVAC/B2: R57.1, U13.3
/HVAC/B3: R60.1, U13.4
/HVAC/B4: R58.1, U13.5
/HVAC/B5: R61.1, U13.6
/HVAC/B6: Q3.3, R59.1, U13.7
/HVAC/B7: Q8.3, R63.1, U13.8
/HVAC/H-Bridge/C1: Q9.3, Q11.1, Q14.1, R65.1
/HVAC/H-Bridge/C2: Q10.3, Q17.1, Q20.1, R67.1
/HVAC/sheet607B7BA9/C1: Q21.3, Q35.1, Q36.1, R81.1
/HVAC/sheet607B7BA9/C2: Q22.3, Q37.1, Q38.1, R83.1
/HVAC/sheet60537A7E/C1: Q15.3, Q27.1, Q28.1, R73.1
/HVAC/sheet60537A7E/C2: Q16.3, Q29.1, Q30.1, R75.1
/HVAC/sheet60537FF7/C1: Q18.3, Q31.1, Q32.1, R77.1
/HVAC/sheet60537FF7/C2: Q19.3, Q33.1, Q34.1, R79.1
/HVAC/sheet6051923C/C1: Q12.3, Q23.1, Q24.1, R69.1
/HVAC/sheet6051923C/C2: Q13.3, Q25.1, Q26.1, R71.1
/IGNITION: J6.26, J8.6, R1.2
/IGNITION_SENSE: R6.1, U1.8, U9.8
/INSIDE_AIR_TEMP: J8.3, R47.1, U15.4
/INSIDE_AIR_TEMP_BLOWER: J8.21, Q4.3
/INTA: U9.10, U13.20
/INTB: U9.11, U13.19
/J1850: D9.1, J6.25, J8.1, R28.2
/J1850_RX: R30.2, U8.8, U9.27
/J1850_TX: R29.1, U9.26
/LEFT_AIR_TEMP_CONTROL_A: J6.1, J6.2, Q11.3, Q14.3
/LEFT_AIR_TEMP_CONTROL_B: J6.3, J6.4, Q17.3, Q20.3
/LF+: J7.17, J7.18, J44.4, U7.9
/LF-: J7.19, J7.20, J44.3, U7.7
/LOWER_LEFT_AIR_TEMP: J6.22, R52.1, U14.5
/LOWER_RIGHT_AIR_TEMP: J6.21, R51.1, U14.4
/LR+: J7.15, J7.16, J45.1, U7.17
/LR-: J7.13, J7.14, J45.2, U7.19
/MAIN_EN: R11.1, U6.1, U9.30
/MAIN_POWER: C9.1, D7.2, J6.33, J6.34, J10.1, R16.1, U6.4
/MODE_A: J6.9, J6.10, Q27.3, Q28.3
/MODE_B: J6.11, J6.12, Q29.3, Q30.3
/Microcontroller/IO2: R35.1, U9.24
/PASSENGER_HEATED_SEAT_STATUS: J8.2, R62.1
/PASSENGER_SEAT_TEMP_CONTROL: J8.12, Q37.3, Q38.3
/PASSENGER_SUNLOAD: J8.13, R55.1, U16.4
/PROG: C40.1, PROG1.1, Q39.2, R33.1, U9.25
/Power/MAIN_POWER_IN: C6.1, U2.3, U2.4, U6.2
/REAR_DEFOG: J8.19, Q5.3
/RECIRCULATION_A: J6.13, J6.14, Q31.3, Q32.3
/RECIRCULATION_B: J6.15, J6.16, Q33.3, Q34.3
/RF+: J7.21, J7.22, J44.2, U7.5
/RF-: J7.23, J7.24, J44.1, U7.3
/RIGHT_AIR_TEMP_CONTROL_A: J6.5, J6.6, Q23.3, Q24.3
/RIGHT_AIR_TEMP_CONTROL_B: J6.7, J6.8, Q25.3, Q26.3
/RR+: J7.11, J7.12, J45.3, U7.21
/RR-: J7.9, J7.10, J45.4, U7.23
/RXD: J46.4, R46.1, R85.2, U9.34, U12.3
/SCL: J43.4, R37.1, U9.36, U10.6, U13.12, U14.10, U15.10, U16.1, U16.10
/SDA: J43.3, R36.2, U9.33, U10.1, U13.13, U14.9, U15.9, U16.9
/SENSE1: J8.22, R7.1, U1.6, U9.16
/TRIGGER1: J8.20, R2.2
/TXD: J46.3, R45.2, U9.35, U12.4
/UPPER_LEFT_AIR_TEMP: J8.17, R50.1, U15.7
/UPPER_RIGHT_AIR_TEMP: J8.5, R49.1, U15.6
/USB/D+: J15.3, J16.3, U12.6
/USB/D-: J15.2, J16.4, U12.7
/WHEEL_CONTROLS_SIGNAL: J6.23, R8.2, U9.9
/WHEEL_CONTROLS_SUPPLY: D1.1, J6.24
GND: C1.2, C2.2, C3.2, C4.2, C5.2, C6.2, C7.2, C8.2, C9.2, C10.2, C11.1, C12.1, C17.2, C18.2, C19.2, C20.1, C21.2, C22.2, C23.2, C24.2, C25.2, C26.2, C27.2, C28.2, C33.2, C34.2, C35.2, C36.2, C37.2, C38.2, C39.2, C40.2, C41.2, C42.2, C43.2, C44.2, D2.2, D8.2, D13.3, EN1.2, FACT1.2, J1.1, J2.1, J3.1, J4.1, J5.11, J5.12, J6.30, J6.35, J6.36, J6.37, J6.38, J6.39, J6.40, J7.33, J7.34, J7.35, J7.36, J7.37, J7.38, J7.39, J7.40, J8.7, J8.24, J8.25, J8.26, J8.33, J8.34, J8.35, J8.36, J8.37, J8.38, J8.39, J8.40, J9.2, J9.3, J10.2, J10.3, J11.2, J11.3, J15.5, J16.2, J42.1, J42.2, J43.1, J46.1, PROG1.2, Q1.2, Q1.4, Q3.2, Q4.2, Q5.2, Q6.2, Q7.2, Q8.2, Q9.2, Q10.2, Q12.2, Q13.2, Q14.2, Q15.2, Q16.2, Q18.2, Q19.2, Q20.2, Q21.2, Q22.2, Q24.2, Q26.2, Q28.2, Q30.2, Q32.2, Q34.2, Q36.2, Q38.2, R4.2, R5.1, R8.1, R9.2, R13.2, R15.2, R17.2, R18.2, R19.2, R20.2, R27.1, R35.2, R39.1, R40.1, SGND1.1, U1.2, U1.4, U1.5, U1.7, U2.5, U3.2, U4.3, U5.3, U6.3, U7.1, U7.2, U7.8, U7.18, U7.24, U8.2, U8.4, U8.7, U9.1, U9.15, U9.38, U9.39, U10.2, U10.7, U11.1, U12.8, U13.10, U13.15, U13.16, U13.17, U14.3, U15.1, U15.3, U16.3
GNDS: SGND1.2, T1.3, T2.3, T3.3, T4.3, U7.13
unnamed: C13.1, U7.11
unnamed: C13.2, R23.1
unnamed: C14.1, U7.12
unnamed: C14.2, R24.1
unnamed: C15.1, U7.15
unnamed: C15.2, R25.1
unnamed: C16.1, U7.14
unnamed: C16.2, R26.1
unnamed: C26.1, R41.1
unnamed: C27.1, R42.1
unnamed: C37.1, U2.6
unnamed: C41.1, R85.1, U12.5
unnamed: C42.1, Q1.1, U12.9
unnamed: C43.1, Q1.3, U12.10
unnamed: D3.1, R5.2
unnamed: D4.1, R9.1
unnamed: D5.1, R18.1
unnamed: D6.1, R19.1
unnamed: D7.1, R20.1
unnamed: D8.1, D9.2, U8.5
unnamed: D10.1, R32.2
unnamed: D11.1, R33.2
unnamed: D12.1, R34.2
unnamed: Q2.1, R43.1
unnamed: Q2.2, R44.2, U12.16
unnamed: Q3.1, R56.2
unnamed: Q4.1, R57.2
unnamed: Q5.1, R58.2
unnamed: Q6.1, R60.2
unnamed: Q7.1, R61.2
unnamed: Q8.1, R62.2
unnamed: Q9.1, R64.2
unnamed: Q10.1, R66.2
unnamed: Q12.1, R68.2
unnamed: Q13.1, R70.2
unnamed: Q15.1, R72.2
unnamed: Q16.1, R74.2
unnamed: Q18.1, R76.2
unnamed: Q19.1, R78.2
unnamed: Q21.1, R80.2
unnamed: Q22.1, R82.2
unnamed: Q39.1, R44.1
unnamed: Q39.3, R43.2, U12.15
unnamed: R1.1, U1.1
unnamed: R2.1, U1.3
unnamed: R12.2, R13.1, U4.5
unnamed: R14.2, R15.1, U5.5
unnamed: R16.2, R17.1, U6.5
unnamed: R28.1, U8.1
unnamed: R29.2, U8.3
unnamed: R31.2, U8.6
unnamed: R40.2, U3.8

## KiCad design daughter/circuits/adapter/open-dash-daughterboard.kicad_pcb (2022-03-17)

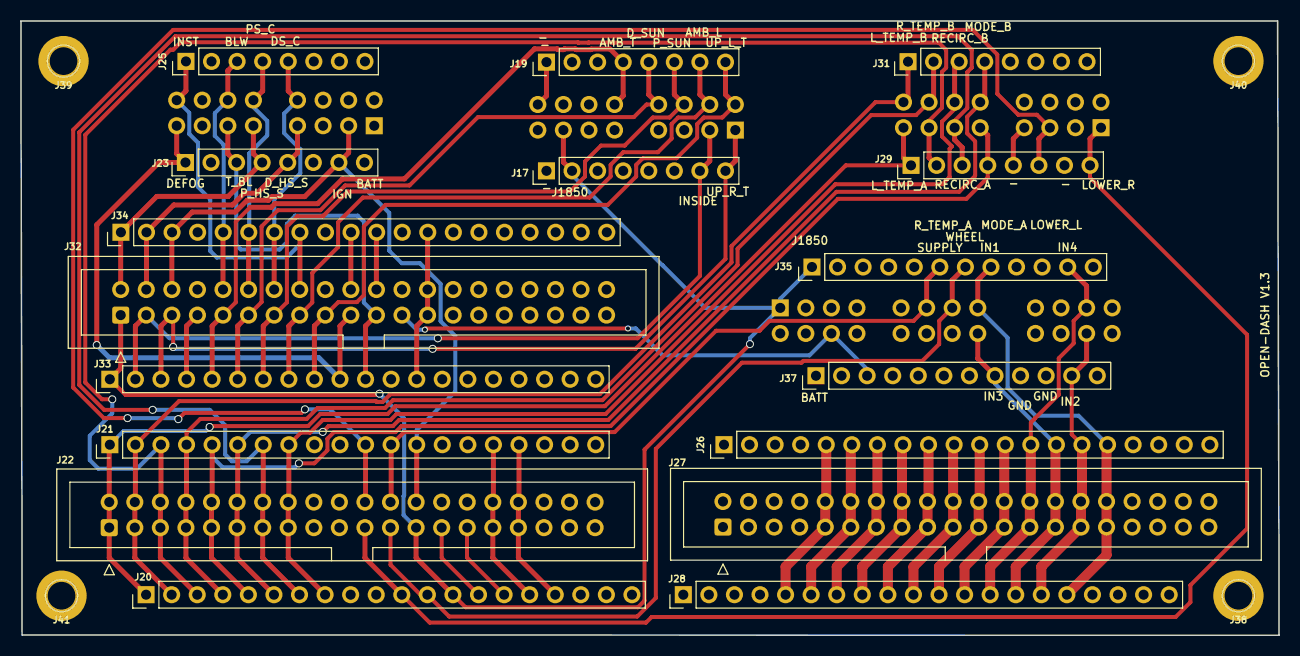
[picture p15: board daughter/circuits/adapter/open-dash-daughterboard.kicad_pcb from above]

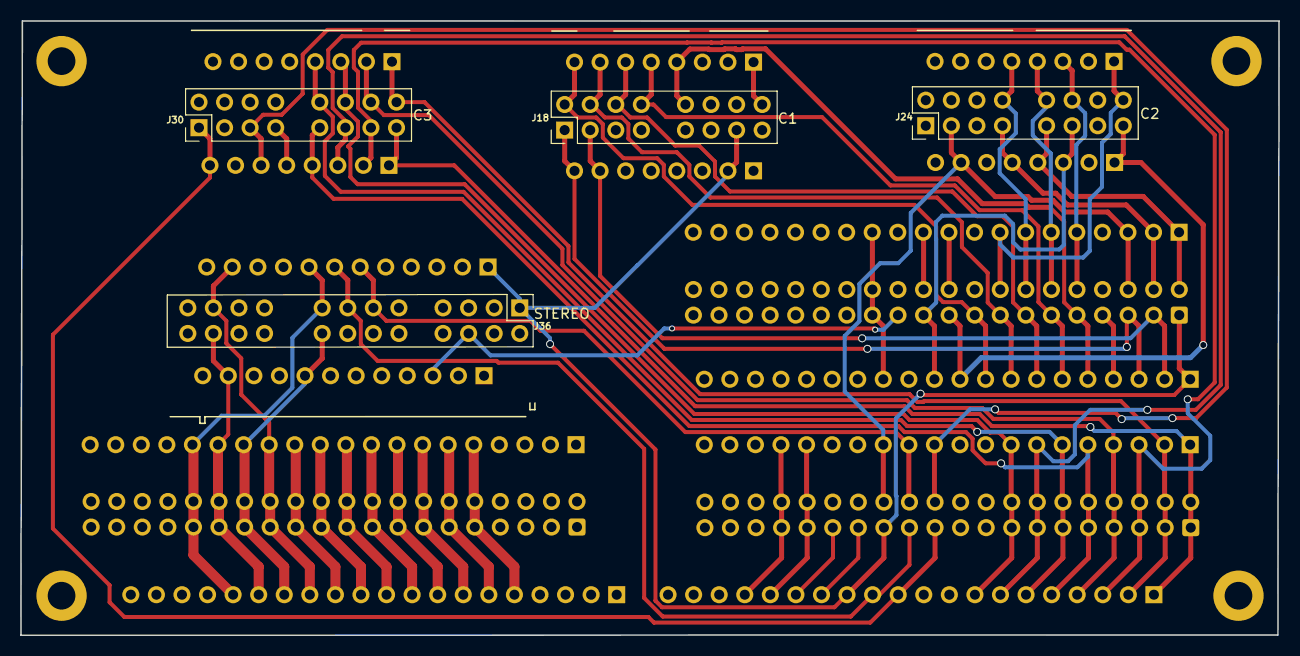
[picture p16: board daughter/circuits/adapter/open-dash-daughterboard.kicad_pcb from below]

Board: 4 copper layers, 125.0 x 61.0 mm, 25 parts (4 on the bottom side), 50 nets.

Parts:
J17, J19, J23, J25, J29, J31: Conn_01x08; PinHeader_1x08_P2.54mm_Vertical
J18: C1; Conn_HVAC
J20, J21, J26, J28, J33, J34: Conn_01x20; PinHeader_1x20_P2.54mm_Vertical
J22, J27, J32: Conn_IDE_40; IDC-Header_2x20_P2.54mm_Vertical
J24: C2; Conn_HVAC
J30: C3; Conn_HVAC
J35, J37: Conn_01x12; PinHeader_1x12_P2.54mm_Vertical
J36: STEREO; Conn_Stereo
J38, J39, J40, J41: Conn_01x01_Female; Mount_Hole

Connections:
/Interface/AMBIENT_AIR_TEMP: J18.12, J19.4, J32.9, J33.5
/Interface/AMBIENT_LIGHT: J18.15, J19.7, J32.15, J33.8
/Interface/AUDIO_IN1: J26.16, J27.31, J27.32, J28.16, J35.8, J36.8
/Interface/AUDIO_IN2: J26.15, J27.29, J27.30, J28.15, J36.23, J37.11
/Interface/AUDIO_IN3: J26.14, J27.27, J27.28, J28.14, J36.20, J37.8
/Interface/AUDIO_IN4: J26.13, J27.25, J27.26, J28.13, J35.11, J36.11
/Interface/BATTERY: J20.9, J20.10, J21.9, J21.10, J21.14, J22.17, J22.18, J22.19, J22.20, J22.28, J23.8, J24.8, J26.1, J26.2, J26.3, J26.4, J27.1, J27.2, J27.3, J27.4, J27.5, J27.6, J27.7, J27.8, J28.1, J28.2, J28.3, J28.4, J32.8, J32.18, J32.27, J32.28, J32.29, J32.30, J32.31, J32.32, J33.14, J33.15, J33.16, J34.4, J34.9, J34.14, J34.15, J34.16, J36.13, J37.1
/Interface/BLOWER_MOTOR: J24.11, J25.3, J32.10, J34.5
/Interface/CAN+: J20.14, J22.27
/Interface/CAN-: J20.15, J22.29
/Interface/DISPLAY_POWER: J20.16, J21.16, J22.31, J22.32
/Interface/DRIVER_HEATED_SEAT_STATUS: J23.5, J24.5, J32.4, J34.2
/Interface/DRIVER_SEAT_TEMP_CONTROL: J24.13, J25.5, J32.14, J34.7
/Interface/DRIVER_SUNLOAD: J18.13, J19.5, J32.11, J33.6
/Interface/EXT_AMP_ON: J32.23, J36.15, J37.3
/Interface/IGNITION: J21.13, J22.26, J23.7, J24.7, J32.6, J34.3
/Interface/INSIDE_AIR_TEMP: J17.7, J18.7, J32.3, J33.2
/Interface/INSIDE_AIR_TEMP_BLOWER: J23.3, J24.3, J32.21, J33.11
/Interface/INSTRUMENT_SUPPLY_VOLTAGE_4: J24.9, J25.1, J32.16, J34.8
/Interface/J1850: J17.2, J18.2, J20.13, J22.25, J32.1, J33.1, J35.1, J36.1
/Interface/LEFT_AIR_TEMP_CONTROL_A: J20.1, J21.1, J22.1, J22.2, J29.1, J30.1
/Interface/LEFT_AIR_TEMP_CONTROL_B: J20.2, J21.2, J22.3, J22.4, J30.9, J31.1
/Interface/LF+: J26.9, J27.17, J27.18, J28.9
/Interface/LF-: J26.10, J27.19, J27.20, J28.10
/Interface/LOWER_LEFT_AIR_TEMP: J21.11, J22.22, J29.6, J30.6
/Interface/LOWER_RIGHT_AIR_TEMP: J20.11, J22.21, J29.8, J30.8
/Interface/LR+: J26.8, J27.15, J27.16, J28.8
/Interface/LR-: J26.7, J27.13, J27.14, J28.7
/Interface/MAIN_POWER: J20.17, J21.17, J22.33, J22.34
/Interface/MODE_A: J20.5, J21.5, J22.9, J22.10, J29.4, J30.4
/Interface/MODE_B: J20.6, J21.6, J22.11, J22.12, J30.12, J31.4
/Interface/PASSENGER_HEATED_SEAT_STATUS: J23.4, J24.4, J32.2, J34.1
/Interface/PASSENGER_SEAT_TEMP_CONTROL: J24.12, J25.4, J32.12, J34.6
/Interface/PASSENGER_SUNLOAD: J18.14, J19.6, J32.13, J33.7
/Interface/REAR_DEFOG: J23.1, J24.1, J32.19, J33.10
/Interface/RECIRCULATION_A: J20.7, J21.7, J22.13, J22.14, J29.3, J30.3
/Interface/RECIRCULATION_B: J20.8, J21.8, J22.15, J22.16, J30.11, J31.3
/Interface/RF+: J26.11, J27.21, J27.22, J28.11
/Interface/RF-: J26.12, J27.23, J27.24, J28.12
/Interface/RIGHT_AIR_TEMP_CONTROL_A: J20.3, J21.3, J22.5, J22.6, J29.2, J30.2
/Interface/RIGHT_AIR_TEMP_CONTROL_B: J20.4, J21.4, J22.7, J22.8, J30.10, J31.2
/Interface/RR+: J26.6, J27.11, J27.12, J28.6
/Interface/RR-: J26.5, J27.9, J27.10, J28.5
/Interface/SENSE1: J32.22, J34.11
/Interface/TRIGGER1: J32.20, J34.10
/Interface/UPPER_LEFT_AIR_TEMP: J18.16, J19.8, J32.17, J33.9
/Interface/UPPER_RIGHT_AIR_TEMP: J17.8, J18.8, J32.5, J33.3
/Interface/WHEEL_CONTROLS_SIGNAL: J20.12, J22.23, J35.7, J36.7
/Interface/WHEEL_CONTROLS_SUPPLY: J21.12, J22.24, J35.6, J36.6
GND: J17.1, J18.1, J18.9, J19.1, J20.18, J20.19, J20.20, J21.15, J21.18, J21.19, J21.20, J22.30, J22.35, J22.36, J22.37, J22.38, J22.39, J22.40, J26.17, J26.18, J26.19, J26.20, J27.33, J27.34, J27.35, J27.36, J27.37, J27.38, J27.39, J27.40, J28.17, J28.18, J28.19, J28.20, J29.5, J29.7, J30.5, J30.7, J32.7, J32.24, J32.25, J32.26, J32.33, J32.34, J32.35, J32.36, J32.37, J32.38, J32.39, J32.40, J33.4, J33.12, J33.13, J33.17, J33.18, J33.19, J33.20, J34.12, J34.13, J34.17, J34.18, J34.19, J34.20, J35.9, J35.10, J35.12, J36.9, J36.10, J36.12, J36.21, J36.22, J37.9, J37.10, J38.1, J39.1, J40.1, J41.1

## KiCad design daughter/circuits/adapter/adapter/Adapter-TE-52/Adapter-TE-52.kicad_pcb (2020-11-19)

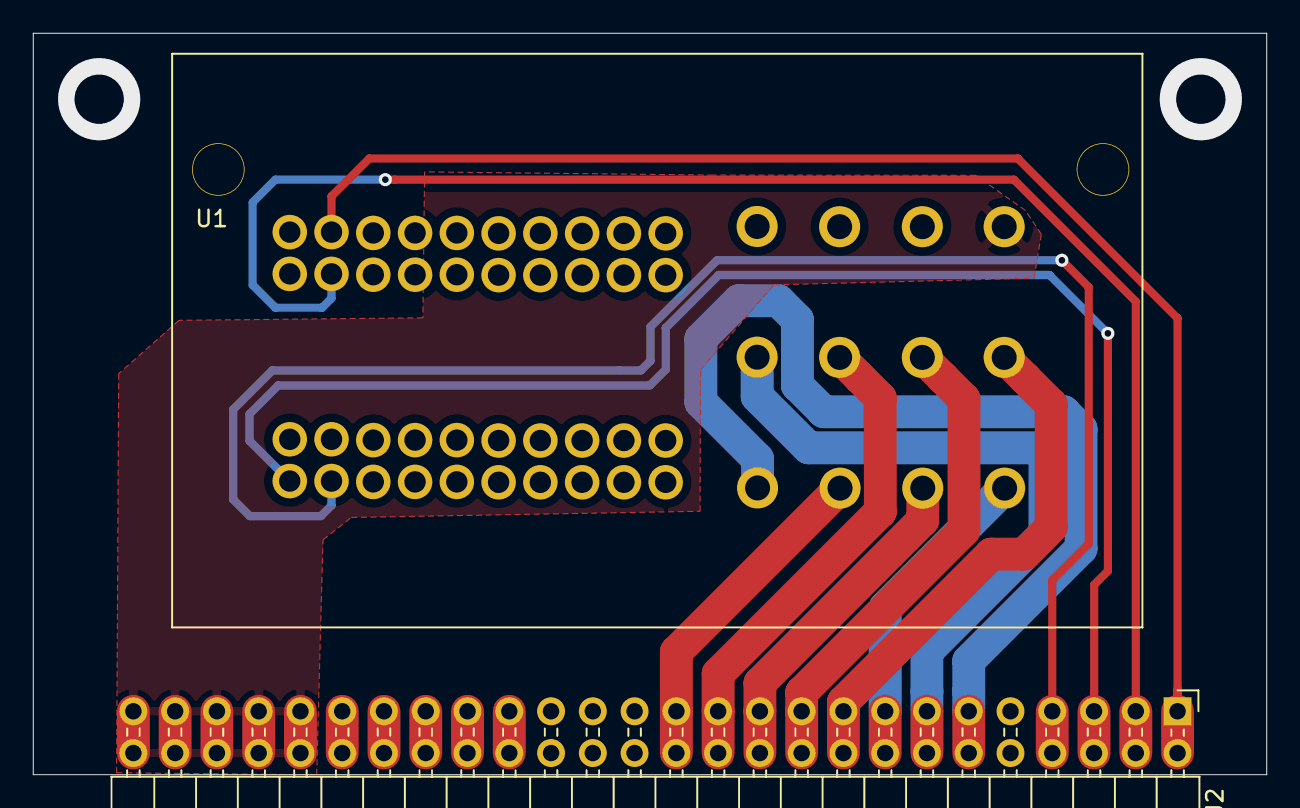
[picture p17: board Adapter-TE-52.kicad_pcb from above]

Board: 2 copper layers, 75.0 x 45.1 mm, 3 parts (1 on the bottom side), 14 nets.

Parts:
LOGO: LOGO
U1: Adapter-TE-52
U2: TE-AUTO-CONN-52

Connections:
/BATTERY: U1.44, U2.44
/CAMERA+: U1.31, U2.31
/CAMERA-: U1.32, U2.32
/CAN+: U1.2, U2.2
/CAN-: U1.12, U2.12
/LF+: U1.47, U2.47
/LF-: U1.51, U2.51
/LR+: U1.48, U2.48
/LR-: U1.52, U2.52
/RF+: U1.46, U2.46
/RF-: U1.50, U2.50
/RR+: U1.45, U2.45
/RR-: U1.49, U2.49
GND: U1.33, U1.43, U2.33, U2.43

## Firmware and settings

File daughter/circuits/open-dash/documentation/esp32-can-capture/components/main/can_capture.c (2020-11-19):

#ifdef _DEBUG
// _DEBUG blinks status LED and prints all frames
#define LOG_LOCAL_LEVEL ESP_LOG_VERBOSE
#endif // _DEBUG
#ifdef _VERBOSE
#define LOG_LOCAL_LEVEL ESP_LOG_VERBOSE
#endif // _VERBOSE

#include "freertos/FreeRTOS.h"
#include "esp_system.h"
#include "esp_event.h"
#include "esp_event_loop.h"
#include "esp_log.h"
#include "esp_timer.h"
#include "driver/gpio.h"
#include "rom/uart.h"
#include "cJSON.h"
#include "CAN.h"

#include <string.h>

// if the dash does not respond, assume it is off
#define DASH_RESPONSE_TIMEOUT         (2000 / portTICK_PERIOD_MS)
// how long to snooze between characters to avoid busy looping
#define DASH_CHARACTER_DELAY          (25 / portTICK_PERIOD_MS)
// master loop queue timeout
#define MASTER_LOOP_PERIOD            (50 / portTICK_PERIOD_MS)
// how long to wait after toggling power before checking status again?
#define DASH_POWERUP_WAIT             (10 * 1000 / portTICK_PERIOD_MS)
#define DASH_POWERDOWN_WAIT           (10 * 1000 / portTICK_PERIOD_MS)

// GPIO assignments
#define GPIO_STATUS_LED               (GPIO_NUM_2)
#define GPIO_CAN_RX                   (GPIO_NUM_4)
// #define GPIO_CAN_TX                   (GPIO_NUM_???)
#define GPIO_MAINBOARD_SOFT_POWER     (GPIO_NUM_5)
#define GPIO_DISPLAY_POWER            (GPIO_NUM_15)
#define GPIO_AUDIO_AMP_POWER          (GPIO_NUM_16)
#define GPIO_MAINBOARD_POWER          (GPIO_NUM_18)

#define KEY_POSITION_MASK             0x0000f00000000f00
#define KEY_POSITION_OFF              0x0000100000000b00
#define KEY_POSITION_START            0x0000c00000000b00
#define KEY_POSITION_RUN              0x0000400000000b00

TaskHandle_t xBlink = NULL;
bool dash_wait_flag = false;

enum eIgnitionState {
  IgnitionOff,
  IgnitionRun,
  IgnitionStart,
  IgnitionUnknown,
} IgnitionState = IgnitionUnknown;

const char * get_ignition_state_label(enum eIgnitionState ignition_state) {
  switch (ignition_state) {
    case IgnitionOff: return "Off";
    case IgnitionRun: return "Run";
    case IgnitionStart: return "Start";
    case IgnitionUnknown: return "Unknown";
  }
  return "what";
}

enum eDashState {
  DashTimedOut,
  DashOn,
  DashUnknown,
} DashState = DashUnknown;

const char * get_dash_state_label(enum eDashState dash_state) {
  switch (dash_state) {
    case DashTimedOut: return "TimedOut";
    case DashOn: return "On";
    case DashUnknown: return "Unknown";
  }

  return "what";
}

CAN_device_t CAN_cfg = {0};

void initialize_gpio() {
  gpio_set_direction(GPIO_STATUS_LED, GPIO_MODE_OUTPUT);
  gpio_set_direction(GPIO_MAINBOARD_SOFT_POWER, GPIO_MODE_OUTPUT);
  gpio_set_direction(GPIO_DISPLAY_POWER, GPIO_MODE_OUTPUT);
  gpio_set_direction(GPIO_AUDIO_AMP_POWER, GPIO_MODE_OUTPUT);
  gpio_set_direction(GPIO_MAINBOARD_POWER, GPIO_MODE_OUTPUT);
}

/***
apply power to peripherals
***/
void apply_dash_power() {
  gpio_set_level(GPIO_DISPLAY_POWER, 0); //display power
  gpio_set_level(GPIO_AUDIO_AMP_POWER, 0); //audio amp power
  gpio_set_level(GPIO_MAINBOARD_POWER, 0); //mainboard power
  gpio_set_level(GPIO_MAINBOARD_SOFT_POWER, 0); //mainboard softpower
}

esp_err_t event_handler(void *ctx, system_event_t *event)
{
  // printf("event: %s\n", fmt_event_id(event->event_id));
  return ESP_OK;
}

/***
TODO: the documentation discourages uart_rx_one_char

read a string from the serial port, until newline (either '\r' or '\n'), outsize, or timeout

Parameters:
out is where to store the characters
outsize is the maximum number of characters to read. callers should leave space for a terminal null.
xTickDelay is how long to sleep after each character to avoid busy looping
xTicksTimeout is how soon we should quit if we did not reach outsize characters, reset after each character.

Return value: number of characters stored (excluding terminal null).

This is blocking and as such is meant to be used from a separate task.
***/
size_t read_uart_string(char * out, size_t outsize) {
  char * outp = out;
  unsigned char in;
  clock_t xTimeout = xTaskGetTickCount() + DASH_RESPONSE_TIMEOUT;

  while (xTaskGetTickCount() < xTimeout && 0 < outsize) {
    if (OK == uart_rx_one_char(&in)) {
      if ('\r' == in || '\n' == in) {
        break;
      } else {
        *outp ++ = in;
        outsize -= 1;
        xTimeout = xTaskGetTickCount() + DASH_RESPONSE_TIMEOUT;
      }
    }
    vTaskDelay(DASH_CHARACTER_DELAY);
  }

  *outp = 0;

  return outp - out;
}

/***
given a JSON string from the dash, populate an sInternalMessage
return non-zero if filled in (even invalid), zero if no message
primarily looking for:
{"type":"status","payload":{"power_state":true}}
***/
enum eDashState interpret_JSON_message(char * json_string) {
  enum eDashState retval = DashUnknown;
  cJSON * root = cJSON_Parse(json_string);
  if (root) {
    cJSON * type = cJSON_GetObjectItem(root, "type");
    if (type) {
      if (cJSON_String == type->type) {
        if (0 == strcmp("status", type->valuestring)) {
          cJSON * payload = cJSON_GetObjectItem(root, "payload");
          if (payload) {
            cJSON * power_state = cJSON_GetObjectItem(payload, "power_state");
            if (power_state) {
              if (cJSON_True == power_state->type) {
                retval = DashOn;
              }
            } else {
              ESP_LOGW("json", "power_state key missing from payload of '%s'", json_string);
            }
          } else {
            ESP_LOGW("json", "payload key missing from '%s'", json_string);
          }
        } else {
          ESP_LOGW("json", "wrong type '%s' in '%s'", type->valuestring, json_string);
        }
      } else {
        ESP_LOGW("json", "type wrong type in '%s': %02x", json_string, type->type);
      }
    } else {
      ESP_LOGW("json", "type key missing from '%s'", json_string);
    }
    cJSON_Delete(root);
  } else {
    ESP_LOGW("json", "failed to parse JSON response '%s'", json_string);
  }

  return retval;
}

/***
wait for one message from the serial port, or set DashTimedOut
***/
enum eDashState query_dash_power_state() {
  char dash_input[100];
  enum eDashState retval = DashTimedOut;

  ESP_LOGI("query", "querying dash...");

  printf("{\"type\":\"status\",\"payload\":{\"get_power_state\":true}}\n");

  if (0 < read_uart_string(dash_input, sizeof(dash_input))) {
    retval = interpret_JSON_message(dash_input);
  } else {
    ESP_LOGI("query", "dash response timed out (%d ms)", DASH_RESPONSE_TIMEOUT * portTICK_PERIOD_MS);
  }

  return retval;
}

/***
"press the button" for one second
***/
void toggle_dash_power() {
  gpio_set_level(GPIO_MAINBOARD_SOFT_POWER, 1);
  vTaskDelay(1000 / portTICK_PERIOD_MS);
  gpio_set_level(GPIO_MAINBOARD_SOFT_POWER, 0);
}

/***
these two are the same for now, but could be different later
***/
void turn_dash_off() {
  ESP_LOGI("power", "turning dash off... (%0.2fs wait)", (1.0 * DASH_POWERDOWN_WAIT * portTICK_PERIOD_MS) / 1000.0);
  toggle_dash_power();
  vTaskDelay(DASH_POWERDOWN_WAIT);
  ESP_LOGI("power", "powerdown wait complete");
}

void turn_dash_on() {
  ESP_LOGI("power", "turning dash on... (%0.2fs wait)", (1.0 * DASH_POWERUP_WAIT * portTICK_PERIOD_MS) / 1000.0);
  toggle_dash_power();
  dash_wait_flag = true;
  vTaskDelay(DASH_POWERUP_WAIT);
  dash_wait_flag = false;
  ESP_LOGI("power", "powerup wait complete");
}

/***
execute the state change operator
***/
void change_dash_state(enum eDashState newstate) {
  switch (newstate) {
    case DashOn:
      if (!dash_wait_flag)  {
        ESP_LOGI("power", "waiting on dash to boot");
        break;
      }
      turn_dash_on();
      break;

    case DashTimedOut:
      //turn_dash_off(); //turning off from the OS via CAN
      break;

    default:
      break;
  }
}

/***
transition the dash's state from a specific current state.
if the precondition (current state) is not met, no transition occurs
***/
void update_dash_state(enum eDashState precondition, enum eDashState postcondition) {
  if (DashState == precondition) {
    change_dash_state(postcondition);
  } else {
    ESP_LOGI("power", "state change from %s to %s fails to meet precondition %s", get_dash_state_label(DashState), get_dash_state_label(postcondition), get_dash_state_label(precondition));
  }
}

/***
pulse the status LED
***/
void pulse_ms(int pulse_count, int high_ms, int low_ms) {
  for (; pulse_count >= 0; pulse_count -= 1) {
    gpio_set_level(GPIO_STATUS_LED, 1);
    vTaskDelay(high_ms / portTICK_PERIOD_MS);
    gpio_set_level(GPIO_STATUS_LED, 0);
    if (pulse_count > 0) {
      vTaskDelay(low_ms / portTICK_PERIOD_MS);
    }
  }
}

/***
block until dash tells us to blink once
***/
void task_BlinkOnce(void * pvParameters) {
  while (1) {
    ulTaskNotifyTake(pdTRUE, portMAX_DELAY);
    pulse_ms(3, 100, 100);
  }
}

/***
monitor and maintain the dash state based on the current ignition state
***/
void task_Dash(void *pvParameters) {
  while (1) {
    DashState = query_dash_power_state();
    switch (DashState) {
      case DashOn:
        xTaskNotifyGive(xBlink);
        ESP_LOGI("dash", "power state: on");
        break;
      case DashTimedOut: ESP_LOGI("dash", "timed out"); break;
      default: ESP_LOGW("dash", "invalid power state");
    }

    switch (IgnitionState) {
      case IgnitionRun:
      case IgnitionStart:
        update_dash_state(DashTimedOut, DashOn);
        break;

      case IgnitionOff:
        update_dash_state(DashOn, DashTimedOut);
        break;

      case IgnitionUnknown:
        break;
    }
  }
}

/***
return this frame's IgnitionStatus, or IgnitionUnknown if it is not an ignition frame
***/
enum eIgnitionState check_ignition_status(const CAN_frame_t * frame) {
  if (CAN_RTR != frame->FIR.B.RTR) {
    switch (frame->MsgID) {
      case 0x6214000:
        switch (frame->data.u64 & KEY_POSITION_MASK) {
          case KEY_POSITION_OFF: return IgnitionOff;
          case KEY_POSITION_RUN: return IgnitionRun;
          case KEY_POSITION_START: return IgnitionStart;
          default: return IgnitionUnknown;
        }
        break;
      case 0x6284000: break; // mute from steering wheel
      case 0x6314018: break; // gear change
      case 0xc214003: // clock, DLC=6 ignore the last 2 bytes
        // 2353210120170000 // Jan 21, 2017, 23:53
        // HHMMddmmYYyy
        break;
    }
  }
  return IgnitionUnknown;
}

/***
wrap this in JSON and send to dash via serial link
***/
void forward_frame(const CAN_frame_t * frame, const unsigned int ctr) {
  int64_t ticks = esp_timer_get_time();
  printf("{\"type\": \"CAN\", \"payload\": {\"message_id\": \"0x%08x\", \"message\": {\"l32\": \"0x%08x\", \"h32\": \"0x%08x\"}, \"length\": %d, \"ticks\": {\"l32\": \"0x%08x\", \"h32\": \"0x%08x\"}, \"counter\": %u}}\n",
    frame->MsgID, frame->data.u32[0], frame->data.u32[1],
    frame->FIR.B.DLC, (uint32_t)(ticks & 0xffffffff), (uint32_t)((ticks >> 32) & 0xffffffff),
    ctr
  );
}

// 64-bit endian reversal
// <https://stackoverflow.com/a/21507710> 2018-06-02
uint64_t swapLong(uint64_t x) {
    x = (x & 0x00000000FFFFFFFF) << 32 | (x & 0xFFFFFFFF00000000) >> 32;
    x = (x & 0x0000FFFF0000FFFF) << 16 | (x & 0xFFFF0000FFFF0000) >> 16;
    x = (x & 0x00FF00FF00FF00FF) << 8  | (x & 0xFF00FF00FF00FF00) >> 8;
    return x;
}

/***
receive CAN bus messages
let ignition on/off messages update car power state
if dash power state is on then transmit (printf) JSON-wrapped copies of non-ignition messages

based on <http://www.barth-dev.de/can-driver-esp32/> and
<http://www.barth-dev.de/wp-content/uploads/2017/01/ESP32_CAN_demo.zip>
as accessed 2018-04-26
***/
void task_CAN (void *pvParameters) {
  //frame buffer
  CAN_frame_t __RX_frame;

  // configure CAN receiver
  CAN_cfg.rx_queue = xQueueCreate(10, sizeof(CAN_frame_t));
  CAN_cfg.rx_pin_id = GPIO_CAN_RX;
  CAN_cfg.speed = 50;

  //start CAN module
  {
    int ret;
    if (0 != (ret = CAN_init())) {
      ESP_LOGE("canbus", "!!! CAN_init failed with %d\n", ret);
      vTaskDelay(1500 / portTICK_PERIOD_MS);
      esp_restart();
    }
  }

  ESP_LOGD("canbus", "Entering CAN loop");
  for (unsigned long ctr = 0; ;) {
    if (pdTRUE == xQueueReceive(CAN_cfg.rx_queue,&__RX_frame, 100 / portTICK_PERIOD_MS)) {
      // RTR frames don't have data
      if (CAN_RTR != __RX_frame.FIR.B.RTR) {
        // ESP32 CAN data payloads are reversed from what we captured with
        // SparkFun CAN Shield
        __RX_frame.data.u64 = swapLong(__RX_frame.data.u64);
      }

      enum eIgnitionState NewIgnitionState = check_ignition_status(&__RX_frame);

      if (NewIgnitionState != IgnitionUnknown) {
        if (NewIgnitionState != IgnitionState) {
          ESP_LOGI("canbus", "ignition state change from %s to %s", get_ignition_state_label(IgnitionState), get_ignition_state_label(NewIgnitionState));
          if (NewIgnitionState == IgnitionRun) {
						dash_wait_flag = true;
	  			}

          if (NewIgnitionState == IgnitionOff) {
						dash_wait_flag = false;
	  			}
          IgnitionState = NewIgnitionState;
          
        } else {
          //ESP_LOGI("canbus", "repeat ignition state %s", get_ignition_state_label(IgnitionState));
        }
      }

      ESP_LOGV("canbus", "queue size: %d", uxQueueMessagesWaiting(CAN_cfg.rx_queue));

      if (1 || DashOn == DashState) {
        forward_frame(&__RX_frame, ctr);
      } else if (CAN_RTR != __RX_frame.FIR.B.RTR) {
        // ESP_LOGV("canbus", "(dash off, q:%d) MsgID: 0x%08x, DLC: %d, Payload: 0x%016llx", uxQueueMessagesWaiting(CAN_cfg.rx_queue), __RX_frame.MsgID, __RX_frame.FIR.B.DLC, __RX_frame.data.u64);
      }

      ctr += 1;
    }
  }
}

void app_main(void) {
#ifdef _DEBUG
  esp_log_level_set("*", ESP_LOG_INFO);
#else // !_DEBUG
  esp_log_level_set("*", ESP_LOG_ERROR);
#endif // _DEBUG

#ifdef _VERBOSE
  // this prints *every* CAN message (except RTR frames which have no data)
  esp_log_level_set("canbus", ESP_LOG_VERBOSE);
#endif // _VERBOSE

  ESP_ERROR_CHECK( esp_event_loop_init(event_handler, NULL) );

  initialize_gpio();
  apply_dash_power();

  xTaskCreate(task_Dash, "Dash", 2048, NULL, 5, NULL);
  xTaskCreate(task_CAN, "CAN", 2048, NULL, 5, NULL);
  xTaskCreate(task_BlinkOnce, "blink", configMINIMAL_STACK_SIZE, NULL, 5, &xBlink);

  while (1) {
#ifdef _DEBUG
    gpio_set_level(GPIO_STATUS_LED, 1);
    vTaskDelay(25 / portTICK_PERIOD_MS);
    gpio_set_level(GPIO_STATUS_LED, 0);
    vTaskDelay(1475 / portTICK_PERIOD_MS);
#else // !_DEBUG
    vTaskSuspend(NULL);
#endif // _DEBUG
  }
}

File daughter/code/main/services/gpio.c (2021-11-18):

#include <stdio.h>
#include <string.h>
#include <stdlib.h>
#include "freertos/FreeRTOS.h"
#include "freertos/task.h"
#include "freertos/queue.h"
#include "driver/gpio.h"
#include "driver/gpio.h"
#include <string.h>

#define IGNITION_WIRE_IO CONFIG_IGNITION_WIRE_IO
#define MAIN_POWER_IO CONFIG_MAIN_POWER_IO
#define DISPLAY_POWER_IO CONFIG_DISPLAY_POWER_IO
#define AUDIO_STBY_IO CONFIG_AUDIO_STBY_IO
#define AUDIO_MUTE_IO CONFIG_AUDIO_MUTE_IO
#define J1850_INPUT_PIN CONFIG_J1850_INPUT_PIN
#define J1850_OUTPUT_PIN CONFIG_J1850_OUTPUT_PIN
#define J1850_DEBUG_PIN 14
#define EXT_AMP_IO 27

#define INTA_GPIO 25
#define INTB_GPIO 26

#define GPIO_OUTPUT_PIN_SEL  ((1ULL<<J1850_DEBUG_PIN) | (1ULL<<J1850_OUTPUT_PIN) | (1ULL<<MAIN_POWER_IO) | (1ULL<<EXT_AMP_IO) | (1ULL<<DISPLAY_POWER_IO) | (1ULL<<AUDIO_STBY_IO) | (1ULL<<AUDIO_MUTE_IO))
#define GPIO_INPUT_PIN_SEL  ((1ULL<<IGNITION_WIRE_IO) | (1ULL<<J1850_INPUT_PIN) | (1ULL<<INTA_GPIO) | (1ULL<<INTA_GPIO))
#define ESP_INTR_FLAG_DEFAULT 0

#define SDA_GPIO 21
#define SCL_GPIO 22


// static void IRAM_ATTR intr_handler(void *arg)
// {
//     printf("Interrupt!\n");
// }

void gpio_main(void)
{
    gpio_config_t io_conf;
    io_conf.intr_type = GPIO_INTR_DISABLE;
    io_conf.mode = GPIO_MODE_OUTPUT;
    io_conf.pin_bit_mask = GPIO_OUTPUT_PIN_SEL;
    io_conf.pull_down_en = 0;
    io_conf.pull_up_en = 0;
    gpio_config(&io_conf);

    io_conf.intr_type = GPIO_INTR_ANYEDGE;
    io_conf.pin_bit_mask = GPIO_INPUT_PIN_SEL;
    io_conf.mode = GPIO_MODE_INPUT;
    io_conf.pull_up_en = 0;
    gpio_config(&io_conf);

    gpio_install_isr_service(ESP_INTR_FLAG_DEFAULT);
}

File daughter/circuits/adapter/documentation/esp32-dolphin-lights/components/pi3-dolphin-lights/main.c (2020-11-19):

/*
   This example code is in the Public Domain (or CC0 licensed, at your option.)

   Unless required by applicable law or agreed to in writing, this
   software is distributed on an "AS IS" BASIS, WITHOUT WARRANTIES OR
   CONDITIONS OF ANY KIND, either express or implied.
*/

#include <stdint.h>
#include <string.h>
#include <stdbool.h>
#include <stdio.h>
#include "nvs.h"
#include "nvs_flash.h"
#include "freertos/FreeRTOS.h"
#include "freertos/task.h"
#include "esp_log.h"
#include "esp_bt.h"
#include "esp_bt_main.h"
#include "esp_gap_bt_api.h"
#include "esp_bt_device.h"
#include "esp_spp_api.h"
#include "driver/rmt.h"


// how many lights the message sender expects
#define VIRTUAL_LIGHT_COUNT (395)

// our actual physical demo strip length
#define REAL_LIGHT_COUNT (300)

#define APP_TAG "PI3_MDD_LIGHT"
#define SPP_SERVER_NAME "PI3_BT_SERVER"
#define EXAMPLE_DEVICE_NAME "Pi3 DelivByLight"

#define RMT_TX_CHANNEL RMT_CHANNEL_0
#define RMT_TX_GPIO 17

// RMT_BASECLK_APB is not defined anywhere I can see, assuming default 80MHz
#define MY_RMT_BASECLK_APB (80)

#define RMT_CLK_DIV 1

// these are defined in WS2812 datasheet
#define PULSE_T0H_US (0.35)
#define PULSE_T1H_US (0.7)
#define PULSE_T0L_US (0.8)
#define PULSE_T1L_US (0.6)
#define PULSE_RES_US (50)

#define T0H_TICKS ((int)(MY_RMT_BASECLK_APB * PULSE_T0H_US))
#define T1H_TICKS ((int)(MY_RMT_BASECLK_APB * PULSE_T1H_US))
#define T0L_TICKS ((int)(MY_RMT_BASECLK_APB * PULSE_T0L_US))
#define T1L_TICKS ((int)(MY_RMT_BASECLK_APB * PULSE_T1L_US))
#define RES_TICKS ((int)(MY_RMT_BASECLK_APB * PULSE_RES_US))

// arbitrary upper limit on message size
#define MSGLEN (50)

static const esp_spp_mode_t esp_spp_mode = ESP_SPP_MODE_CB;
static const esp_spp_sec_t sec_mask = ESP_SPP_SEC_NONE;
static const esp_spp_role_t role_slave = ESP_SPP_ROLE_SLAVE;

struct __attribute__((__packed__)) rgb_t {
  unsigned char r, g, b;
};

struct rgb_t pixel[REAL_LIGHT_COUNT] = {0};
// 3 channels (RGB), 8 bits each
rmt_item32_t rmt_pixel[REAL_LIGHT_COUNT][3][8];

void set_pixel_channel(rmt_item32_t * item, int state) {
  item->level0 = 1;
  item->level1 = 0;
  if (0 == state) {
    item->duration0 = T0H_TICKS;
    item->duration1 = T0L_TICKS;
  } else {
    item->duration0 = T1H_TICKS;
    item->duration1 = T1L_TICKS;
  }
}

void write_pixels() {
  int structs = sizeof(rmt_pixel) / sizeof(rmt_pixel[0][0][0]);
  ESP_ERROR_CHECK(rmt_write_items(RMT_TX_CHANNEL, rmt_pixel, structs, true));
}

// copy rgb_t pixel data into rmt_pixel data
void set_pixel_by_index(int index, unsigned char r, unsigned char g, unsigned char b, int write) {
  int bit;
  if (index >= 0 && index < REAL_LIGHT_COUNT) {
    for (bit = 7; bit >= 0; bit -= 1) {
      set_pixel_channel(&(rmt_pixel[index][0][bit]), g & (1 << bit));
      set_pixel_channel(&(rmt_pixel[index][1][bit]), r & (1 << bit));
      set_pixel_channel(&(rmt_pixel[index][2][bit]), b & (1 << bit));
    }
    if (write) {
      write_pixels();
    }
  } else {
    ESP_LOGI(APP_TAG, "pixel index %d out of bounds", index);
  }
}

void all_one_color(unsigned char r, unsigned char g, unsigned char b) {
  int index;
  for (index = 0; index < REAL_LIGHT_COUNT; index += 1) {
    set_pixel_by_index(index, r, g, b, 0);
  }
  write_pixels();
}

void reset_pixels() {
  all_one_color(0, 0, 0);
}

static void ws2812_rmt_tx_init() {
    rmt_config_t config = {};

    config.rmt_mode = RMT_MODE_TX;
    config.channel = RMT_TX_CHANNEL;
    config.clk_div = RMT_CLK_DIV;
    config.gpio_num = RMT_TX_GPIO;
    config.mem_block_num = 1; // don't know what this does but it needs to be so

    config.tx_config.loop_en = 0;
    config.tx_config.carrier_en = 0;
    config.tx_config.idle_output_en = 0;
    config.tx_config.idle_level = 0;

    ESP_ERROR_CHECK(rmt_config(&config));
    ESP_ERROR_CHECK(rmt_driver_install(config.channel, 0, 0));
}

void do_light_range(int low, int high) {
  // per documentation the LOW light is NOT lit but ones afterward are
  // just set them green for now
  reset_pixels();
  int real_low, real_high;
  real_low = REAL_LIGHT_COUNT * (1.0 * low / VIRTUAL_LIGHT_COUNT);
  real_high = REAL_LIGHT_COUNT * (1.0 * high / VIRTUAL_LIGHT_COUNT);

  ESP_LOGI(APP_TAG, "mapping virtual light range (%d,%d] to real light range (%d, %d]", low, high, real_low, real_high);

  if (real_high > 0) {
    int i;
    for (i = real_low + 1; i < real_high; i += 1) {
      set_pixel_by_index(i, 0, 255, 0, 0);
    }

    set_pixel_by_index(i, 0, 255, 0, 1);
  }
}

void process_message(char * msg) {
  char * msg_high;
  int low_end, high_end;
  if ('L' == msg[0]) {
    low_end = strtol(msg + 1, &msg_high, 10);
    if ('H' == msg_high[0]) {
      high_end = strtol(msg_high + 1, NULL, 10);
      ESP_LOGI(APP_TAG, "parsed message Low: %d, High: %d, lighting...", low_end, high_end);

      do_light_range(low_end, high_end);

    } else {
      ESP_LOGE(APP_TAG, "failed to find H in message '%s'", msg);
    }
  } else {
    ESP_LOGE(APP_TAG, "failed to find L in message '%s'", msg);
  }
}

void data_to_string(char * dst, size_t maxlen, unsigned char * src) {
  int i;
  if (dst && src) {
    for (i = 0; i < maxlen && src[i]; i += 1) {
      dst[i] = src[i];
    }
    dst[i] = 0;
  }
}

static void esp_spp_cb(esp_spp_cb_event_t event, esp_spp_cb_param_t *param)
{
    char msgbuf[MSGLEN+1]; // for incoming light-up messages

    switch (event) {
    case ESP_SPP_INIT_EVT:
        ESP_LOGI(APP_TAG, "ESP_SPP_INIT_EVT");
        esp_bt_dev_set_device_name(EXAMPLE_DEVICE_NAME);
        esp_bt_gap_set_scan_mode(ESP_BT_SCAN_MODE_CONNECTABLE_DISCOVERABLE);
        esp_spp_start_srv(sec_mask,role_slave, 0, SPP_SERVER_NAME);
        break;
    case ESP_SPP_DISCOVERY_COMP_EVT:
        ESP_LOGI(APP_TAG, "ESP_SPP_DISCOVERY_COMP_EVT");
        break;
    case ESP_SPP_OPEN_EVT:
        ESP_LOGI(APP_TAG, "ESP_SPP_OPEN_EVT");
        break;
    case ESP_SPP_CLOSE_EVT:
        ESP_LOGI(APP_TAG, "ESP_SPP_CLOSE_EVT");
        break;
    case ESP_SPP_START_EVT:
        ESP_LOGI(APP_TAG, "ESP_SPP_START_EVT");
        break;
    case ESP_SPP_CL_INIT_EVT:
        ESP_LOGI(APP_TAG, "ESP_SPP_CL_INIT_EVT");
        break;
    case ESP_SPP_DATA_IND_EVT:
        ESP_LOGI(APP_TAG, "ESP_SPP_DATA_IND_EVT len=%d handle=%d",
                 param->data_ind.len, param->data_ind.handle);
        esp_log_buffer_hex("",param->data_ind.data,param->data_ind.len);
        data_to_string(msgbuf, (param->data_ind.len < MSGLEN ? param->data_ind.len : MSGLEN), param->data_ind.data);
        ESP_LOGI(APP_TAG, "as string: '%s'", msgbuf);
        process_message(msgbuf);
        break;
    case ESP_SPP_CONG_EVT:
        ESP_LOGI(APP_TAG, "ESP_SPP_CONG_EVT");
        break;
    case ESP_SPP_WRITE_EVT:
        ESP_LOGI(APP_TAG, "ESP_SPP_WRITE_EVT");
        break;
    case ESP_SPP_SRV_OPEN_EVT:
        ESP_LOGI(APP_TAG, "ESP_SPP_SRV_OPEN_EVT");
        break;
    default:
        ESP_LOGI(APP_TAG, "default event");
        break;
    }
}
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

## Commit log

2017-12-31 Added MDD Device Sysinfo.txt file.
2018-01-08 fixed syntax issue in index.js
    [index.js]
2018-01-10 Updated sockets into nwpm
2018-01-10 renamed index.js -> interface.js & tied abort reboot to radio button
2018-01-11 Added required modules folder with files & updated devices folder
2018-01-11 Added webserver.js & some function codes for socket.io
2018-01-18 Connect navigation button to controller
2018-01-18 settings view and angular material cdn path added to index
2018-01-20 Added Src for client,Made changes in dashboard.html with volume button in the footer
2018-01-23 Added back button in the header,Added sample json for remote.js
2018-01-24 fixed bug in switching between play and pause icons
2018-01-24 modified the runScan to return the information to device_list variable
2018-01-26 Added Scan and autoconnect buttons
2018-01-30 use node-main to start web server, and socket.io server
2018-01-30 use node-main to start web server and socket.io
2018-01-31 Added condition to switch views from remote to dashboard Added icons in system page
2018-02-05 updated not needing a max probe count
2018-02-05 increase device ping timeout to 30 seconds
2018-02-05 Added home button and title change accordingly in pages
2018-02-06 update device list after scan
2018-02-06 refresh device list in UI view after initial runScan completes
2018-02-08 add socket.io listener on port 1234 for screenshots from remote
2018-02-15 add sample video
2018-02-15 Added Camera Icon to dashboard Made changes to pandora login form
2018-02-27 added websocket relay for camera stream
2018-02-27 added websocket relay for video stream
2018-02-27 start video streaming when camera page is loaded
2018-03-09 GET JPEG only every frame
2018-03-13 added More button in pandora station playlist to show more songs
2018-03-27 WIP: Switches to remote view automatically on wifi connection
2018-03-28 Finished switching to Remote page when MDD connects
2018-03-29 AM/FM radio UI in place for seeking channels, storing/using presets, switching between bands
2018-04-18 Made number of dashboard columns dynamic based on number of buttons
2018-04-18 Unhide buttons
2018-05-29 Added CAN module that listens for CAN messages from the daughter board and translates them into events based on vehicle-specific definitions
2018-05-30 Added daughter board power state response
2018-05-31 Moved handshake with daughter board from main.js to daughter.js, cleaned up daughter.js, JSON.stringify-ed data before sending to daughter board in daughter.js send method, cleaned up configuration.j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
2018-05-31 Implemented switching to backup camera view when the vehicle is in reverse mode, rewrote the video stream server and devices/camera.js
2018-05-31 Updated CAN module to support translating actions that have a start and end into events (e.g. pressing and holding a volume up button)
2018-06-06 Fixed permissions on source files
    [index.js]
2018-06-11 Increase/decrease volume while holding volume up/down buttons
2018-06-12 Cleaned up footer controller, fixed mute button in footer
2018-06-12 Make footer mute button show the right icon depending on muted state
2018-06-12 Fix mute icon not changing when pressing footer volume buttons
2018-06-12 Wired up CAN seek up/down to amfm service
2020-11-19 Tried electron. Moving back to nwjs.io. Ready to test j1850
    [Adapter-TE-52-B_Cu.gbr, Adapter-TE-52-B_Mask.gbr, Adapter-TE-52-B_Paste.gbr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]
2020-12-13 complete redesign for GM dash, including hvac replacement
    [FM-radio.sch, audio-amplifier.sch, bom.ods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]
2020-12-31 finished layout and routing
    [hvac.sch, j1850.sch, open-dash-daughterboard.sch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]
2021-01-10 MCP IO expander can communicate, working on MAX ADC
2021-01-18 finished drivers for io expander and adc. Made hvac service. Working on serial api.
2021-01-20 made pwm for blower motor, working on uart api
2021-01-22 Added uart json api and input box on the gui to send commands.
2021-01-22 bug fix: input recognize keyboard input
    [gpio.c]
2021-01-26 Extended power service, ready to test
2021-01-27 Added HVAC blower motor levels
2021-01-28 testing new temp actuator task
2021-01-31 working on controlling actuator
2021-02-09 testing temperature control actuator
2021-03-07 0) Switched to h-bridge drivers for hvac 1) Connected ignition sense io 2) MCP config pins and reset 3) Fixed usb resistors 4) Fixed BJT footprint 5) Added car interface pcb for C6 Corvette
    [audio-amplifier.sch, canbus.sch, h-bridge.sch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]
2021-03-10 finished schematic, working on layout
    [audio-amplifier.sch, canbus.sch, h-bridge.sch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]
2021-03-13 finished layout
    [audio-amplifier.sch, h-bridge.sch, hvac.sch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]
2021-03-14 sent v1.2 to fab
    [CANBUS_Messages.ods, canbus.sch, h-bridge.sch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]
2021-03-15 modified break tabs for fab fab house
    [open-dash-daughterboard-B_Cu.gbr, open-dash-daughterboard-B_Mask.gbr, open-dash-daughterboard-B_Paste.gbr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]
2021-04-10 Ready to test new board in vette
2021-04-11 Tested temp control with new h-bridge design, works as expected. Now checking j1850 driver
2021-04-12 Still having timing issues for j1850 protocol
    [j1850.c]
2021-04-19 Added model for c6 corvette housing. Also added code for soft shutdown. Still need to detect main comp current.
    [box.stl, cabinet-old.blend, cabinet-side-left.blend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]
2021-04-20 Fixed heap overflow due to cJSON functions using malloc. Need to free strings generated and use cJSON_Delete on objects.
    [hvac.c, index.js, main.c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]
2021-05-30 Adjusted hvac time actuator drivers
2021-06-03 adjusted j1850 timing with new 100ohm resistor
2021-06-05 Added mode switch timings for head,feet, both and defrost.
2021-06-06 Tweaking uart messages
2021-06-28 Fixed heap overflow in uart function
    [index.js, uart.c]
2021-06-28 Turning on/off ac with ignition to not kill battery.
2021-07-26 Pulsing actuator to prevent over heating
    [hvac.c, index.js, j1850.c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]
2021-08-25 Made struct for actuators
2021-11-13 Added external amp trigger code and circuit to PCB. Made some layout modifications.
    [audio-amplifier.sch, canbus.sch, h-bridge.sch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]
2021-11-13 Fixed a couple small bugs
    [hvac.c, power.c]
2021-11-18 Using npn-pnp high side switch for ext amp trigger.
    [h-bridge.sch, microcontroller.sch, open-dash-daughterboard.sch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]
2022-01-06 new design (v1.3) sent to boa board house
    [Adapter-TE-52-B_Cu.gbr, Adapter-TE-52-B_Mask.gbr, Adapter-TE-52-B_Paste.gbr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]
2022-01-24 send v1.4 to board house. Corrected source-drain on fets.
    [audio-amplifier.sch, h-bridge.sch, microcontroller.sch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]
2022-02-17 updated schematic
    [audio-amplifier.sch, h-bridge.sch, open-dash-daughterboard.kicad_pcb]
2022-06-09 Updated hvac circuit
    [audio-amplifier.kicad_sch, canbus.kicad_sch, hvac.kicad_sch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]
